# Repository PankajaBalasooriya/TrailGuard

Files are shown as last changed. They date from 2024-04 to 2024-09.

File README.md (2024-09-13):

## TrailGuard
Trail Guard is a portable device that monitors various environmental parameters, including air and water quality, using a wide range of sensors. This comprehensive monitoring tool is designed to be valuable for both travelers and residents who are concerned about their environmental conditions.. 

## Table of Contents

## Why "Trail Guard"?

## Features
- **Portable**: Trail Guard is a portable device that can be easily carried around.
- **Comprehensive**: Trail Guard monitors a wide range of air and water quality parameters.
- **User-friendly**: Trail Guard is designed to be user-friendly and easy to use.
- **Real-time monitoring**: Trail Guard provides real-time monitoring of environmental parameters.
- **Alert system**: Trail Guard has an alert system that notifies users of any harmful environmental conditions.

## Hardware Specifications
- **Microcontroller**: Atmega328P-AU
- **Sensors**: 
  - Temperature and Humidity Sensor (DHT11)
  - Air Quality Sensor (MQ2)
  - Water Quality Sensor (PH Sensor)
  - TDS Sensor
  - Turbidity Sensor
  - Dust Sensor (GP2Y1010AU0F)
- **Display**: 0.96 inch OLED Display
- **User Interface**: 2 Push Buttons and LED Indicator

## Software Specifications
- **Programming Language**: C++ (Arduino)
- **IDE**: Arduino IDE
- **Libraries**:
  - Adafruit_Sensor
  - Adafruit_GFX
  - Adafruit_SSD1306
  - DHT
- **PCB Design Software**: Altium Designer
- **3D Modelling Software**: SolidWorks





## PCB design
The PCB design of Trail Guard was done using Altium Designer. The PCB design files are available in the `TrailGuard2.0` folder.

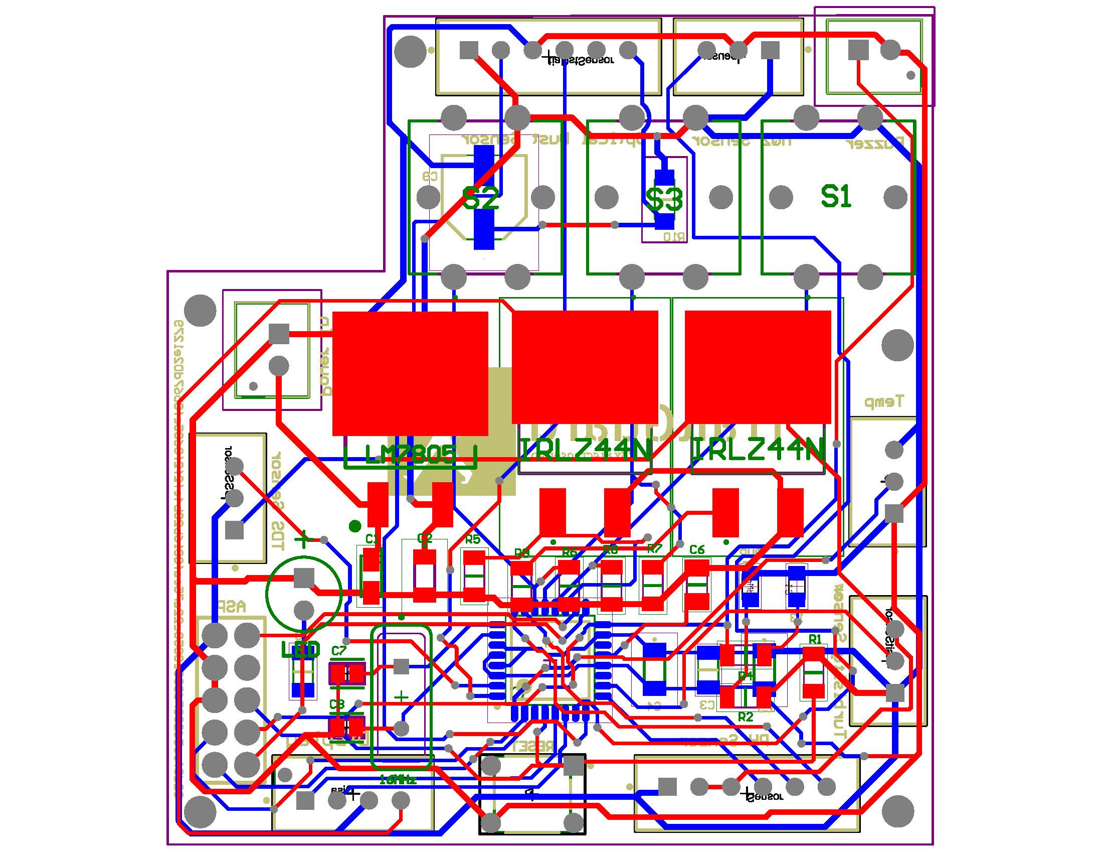
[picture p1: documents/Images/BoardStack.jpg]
PCB Design

<div style="display: flex; justify-content: space-between;">
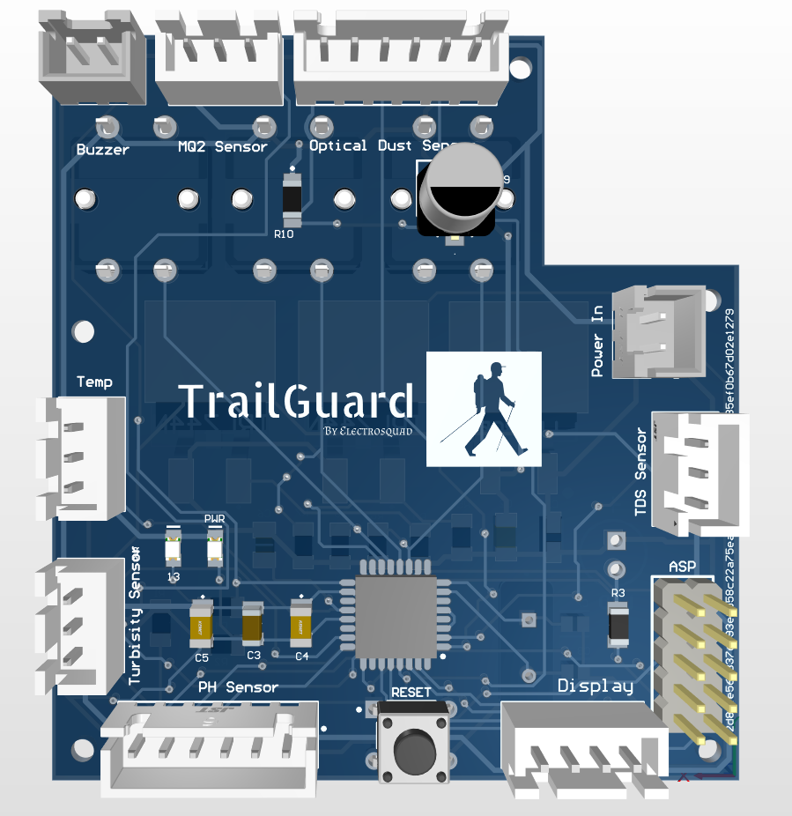
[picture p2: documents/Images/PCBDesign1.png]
    
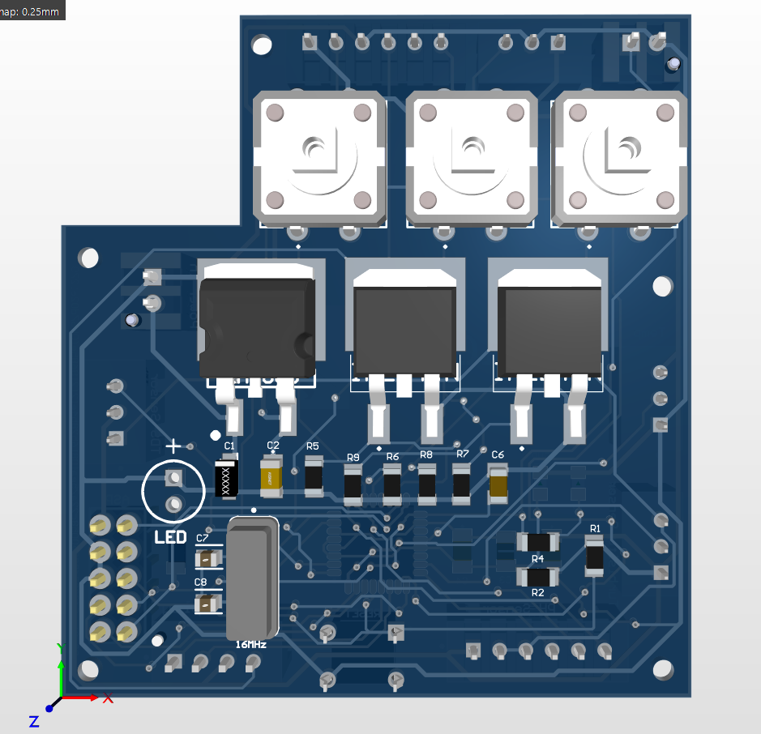
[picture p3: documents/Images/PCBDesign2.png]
    
</div>

## PCB Schematic
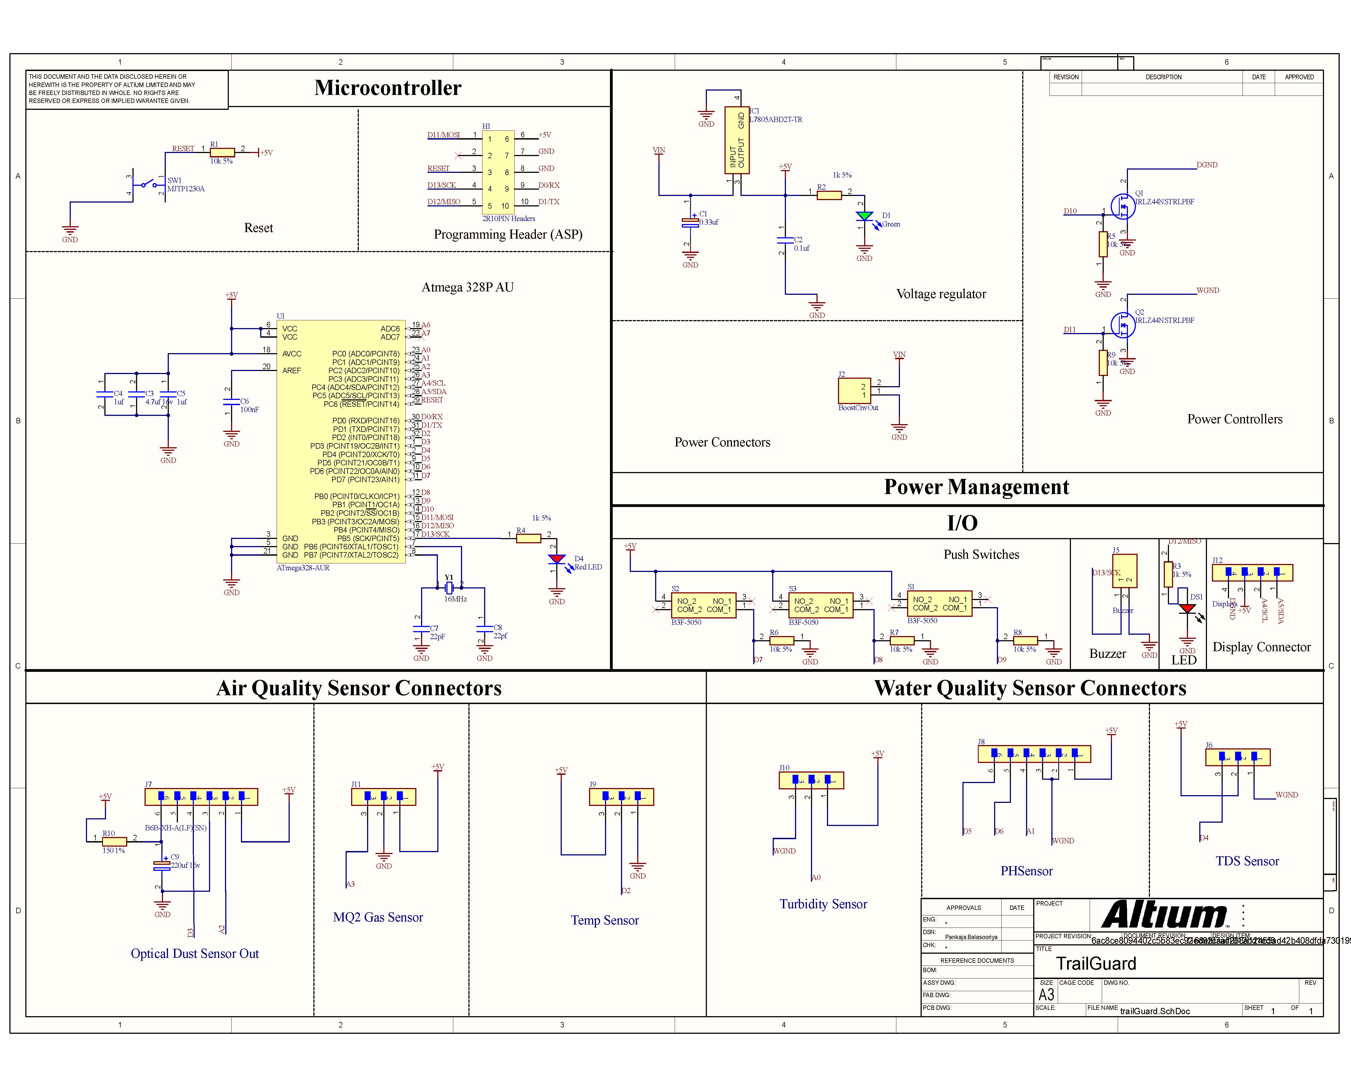
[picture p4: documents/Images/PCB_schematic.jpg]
PCB Schematic


## PCB
<div style="display: flex; justify-content: space-between;">
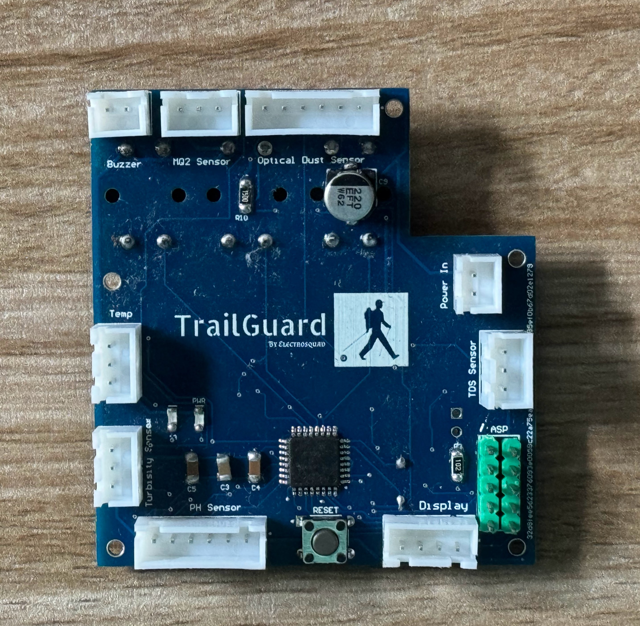
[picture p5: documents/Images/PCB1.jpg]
    
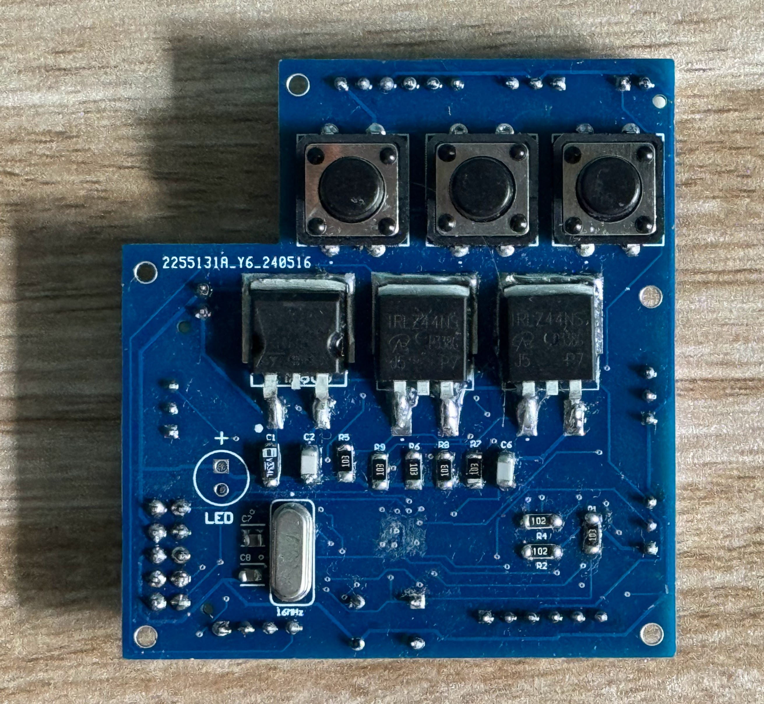
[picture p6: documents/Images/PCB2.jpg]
    
</div>

## SolidWorks Design
<div style="display: flex; justify-content: space-between;">
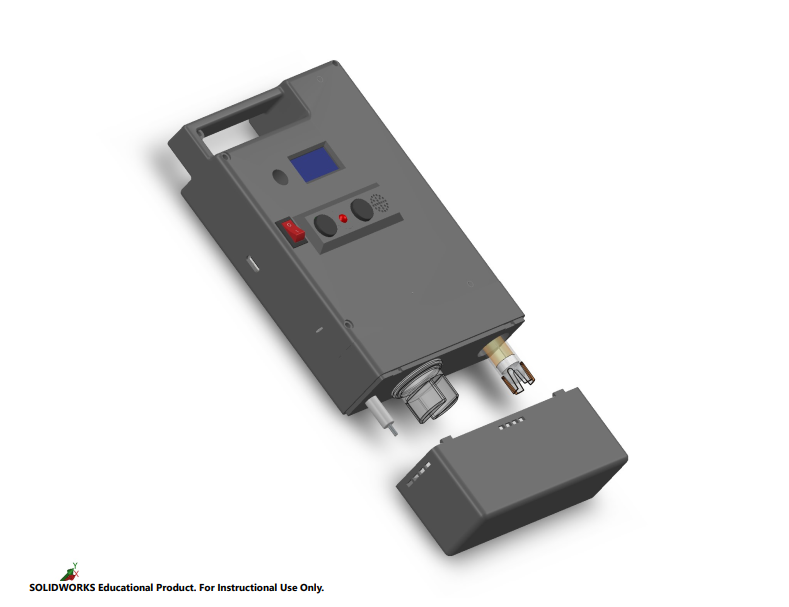
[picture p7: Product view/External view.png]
    
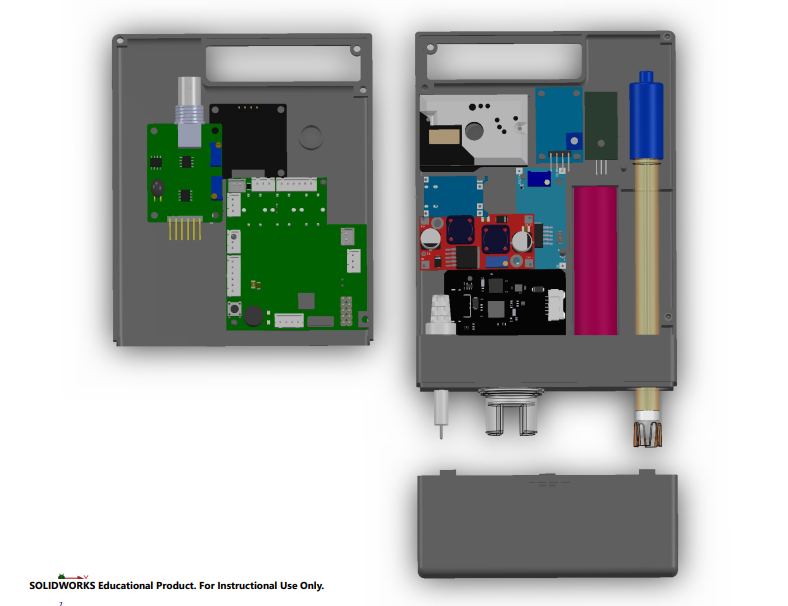
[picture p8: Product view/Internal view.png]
    
</div>

## Product View
<div style="display: flex; justify-content: space-between;">
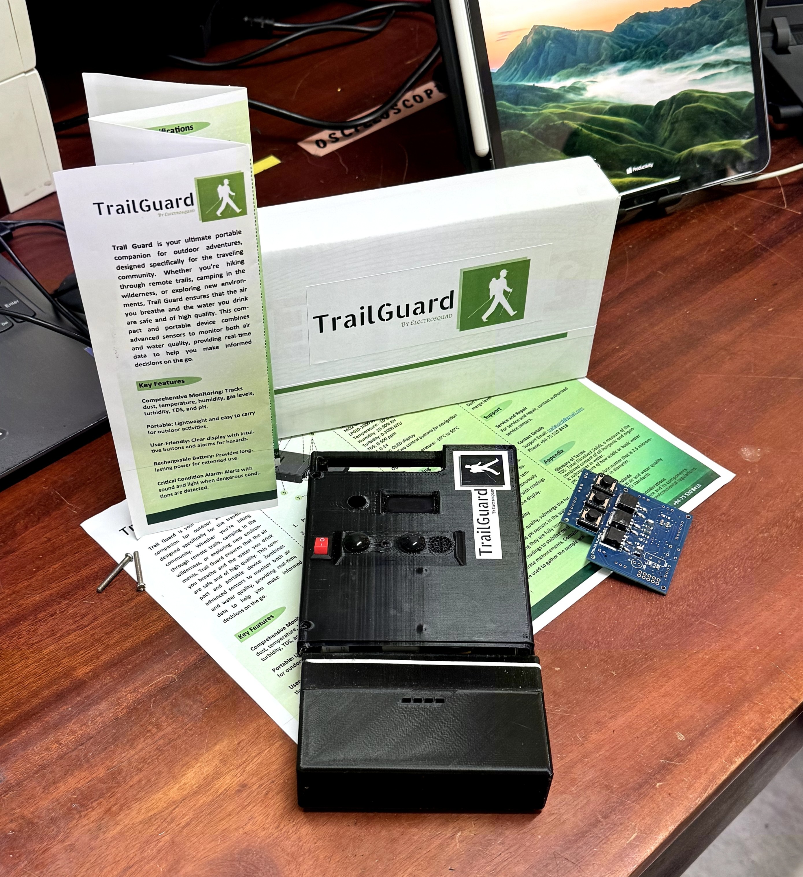
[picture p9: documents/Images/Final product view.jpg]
    
    
</div>

## Team Members
| Name | Index Number |Email|
|---|---|---|
| Balasooriya B A P I | 220054N | balasooriyabapi.22@uom.lk |
| Dewasumithra M P O | 220112R| dewasumithrampo.22@uom.lk |
| Dineshara M C | 220128V |dinesharamc.22@uom.lk|
| Diunugala C H | 220143L | diunugalach.22@uom.lk |

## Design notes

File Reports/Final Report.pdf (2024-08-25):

Department of Electronic and Telecommunication Engineering

## University of Moratuwa, Sri Lanka

EN 1190 - Engineering Design Project

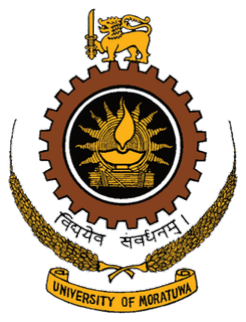
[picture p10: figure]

# TrailGuard

by

# Electrosquad

Balasooriya B A P I | 220054N
Dewasumithra M P O | 220112R
Dineshara M C | 220128V
Diunugala C H | 220143L

## August 25, 2024

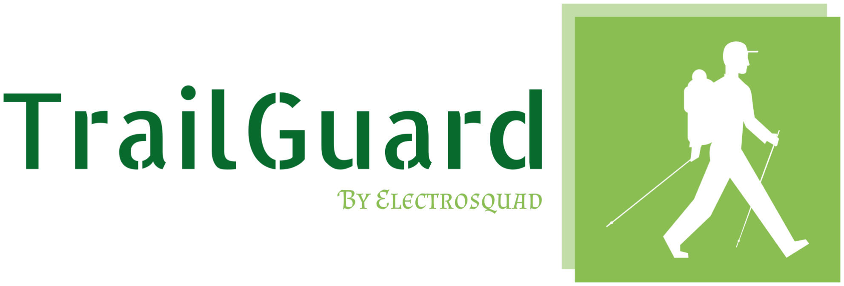
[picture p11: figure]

## Contents

1 Problem Description | 4
2 Feasibility | 6
3 Applications | 7
4 Product Architecture | 8
5 Design and Product Enclosure | 10
6 PCB | 11
7 Final Product | 13
8 Marketing Strategy | 14
9 Task Allocation | 15

10 Project Budget | 15
11 Resources | 16
12 References | 16

## 1 Problem Description

### 1.1 Problem

In today’s rapidly changing environment, outdoor enthusiasts such as hikers, cavers, and travelers face increasing challenges related to environmental conditions. The quality of air and water is not always visible, yet it plays a crucial role in health and safety. Hikers often encounter water sources during their journeys, but determining whether the water is safe for drinking or swimming is difficult without proper equipment. Additionally, exposure to harmful gases, especially in caves or enclosed spaces, can be hazardous. The lack of portable, comprehensive solutions that monitor these vital environmental parameters poses a significant risk to those who venture into nature.

### 1.2 Solution

TrailGuard is a portable device designed to address these challenges by providing real-time monitoring of key environmental parameters such as air quality, water quality, temperature, and humidity. Equipped with a range of sensors, including a TS-300B turbidity sensor, PH4502C pH sensor, DHT11 temperature and humidity sensor, Sharp GP2Y1010AU0F dust sensor, and MQ2 gas sensor, TrailGuard offers a comprehensive solution for assessing environmental conditions. The device also includes a buzzer and LED indicator to alert users to potential dangers, making it a valuable addition to any hiker’s gear. The Atmega328P-AU microcontroller serves as the brain of the device, ensuring efficient operation and control over the various sensors and user interfaces.

### 1.3 Motivation

The motivation behind TrailGuard stems from the growing need for safety and awareness among outdoor enthusiasts. With the increasing popularity of hiking, caving, and other outdoor activities, there is a rising demand for reliable tools that can help individuals assess and respond to environmental risks. TrailGuard aims to empower users with the knowledge they need to make informed decisions about the air they breathe, the water they encounter, and the overall environmental conditions during their adventures. By providing a portable, user-friendly solution, TrailGuard enhances the safety and enjoyment of outdoor experiences.

### 1.4 Justification

The development of TrailGuard is justified by the clear demand for a compact, reliable device that addresses multiple environmental concerns in one package.
To validate the problem and understand the needs and preferences of potential users, we conducted a survey among hikers, adventurers, and students across universities in Sri Lanka. Out of 150 responses, we randomly selected 100 samples for analysis.

80%

20%

Yes
No

Number of people who faced issues due to contaminated air and water

95%
5%

Yes
No

Number of people who like to own a product like our design

93%
7%

Yes
No

Number of people thinks our product will enhance their experience

The survey revealed significant concerns about environmental safety during outdoor activities. Notably, 80% of respondents reported facing issues due to contaminated air and water while traveling. Despite this, only one respondent owned a device capable of measuring water quality.
The majority of participants (95%) expressed a strong interest in owning a product like TrailGuard, and 93% believed that such a device would enhance their overall travel experience.
Furthermore, our research indicated a lack of existing products that offer the same combination of functionalities as TrailGuard. While there are devices available that measure either water or air quality, they tend to be expensive and lack the comprehensive monitoring capabilities of our design. Additionally, social media research highlighted frequent complaints from tourists in the South Asian region about unknowingly drinking contaminated water, leading to unexpected health issues during their travels.
These factors, combined with the positive feedback from our survey, strongly support the need for TrailGuard. The device’s ability to monitor air and water quality, detect harmful gases, and measure temperature and humidity in a single, portable form factor makes it a valuable tool for enhancing safety and enjoyment during outdoor adventures.

## 2 Feasibility

### 2.1 Technical Feasibility

The project technically feasible, and all resource requirements were met easily.
We Designed the electronic circuits and designed the PCB in altium designer. The PCB was manufactured and assembled by a professional PCB manufacturer (JLC PCB). The software was developed using the Arduino IDE, and the final product was tested for functionality and performance. We used Black PLA to 3D print the enclosure for the device. The device was assembled and tested for fit and functionality.

### 2.1.1 Hardware Feasibility

The hardware components required for TrailGuard are readily available and well-suited for the device’s intended functionality. The core of the system is the Atmega328P-AU microcontroller, a robust and reliable choice for managing multiple sensor inputs and controlling the device’s user interface. The selected sensors, including the TS-300B turbidity sensor, PH4502C pH sensor, DHT11 temperature and humidity sensor, Sharp GP2Y1010AU0F dust sensor, MQ2 gas sensor, and Gravity TDS sensor, are all compatible with the Atmega328P-AU and have been widely used in similar applications.

These sensors have been chosen for their accuracy, reliability, and low power consumption, which is critical for a portable device like TrailGuard. The device also incorporates an OLED display, buttons, a buzzer, and an LED indicator, all of which are easily integrated with the microcontroller. The hardware design also includes power-saving features, such as the ability to turn off the display and water sensors when not in use, which extends battery life.

### 2.1.2 Software Feasibility

The software development for TrailGuard primarily involves programming the Atmega328P-AU microcontroller to manage the sensors, process the data, and control the user interface. The microcontroller can be programmed using the Arduino IDE, which is well-documented and widely supported, making it a practical choice for this project.

The software will need to handle real-time data acquisition from multiple sensors, perform basic data processing, and trigger alerts based on predefined thresholds for air and water quality. The user interface, controlled via the OLED display and buttons, will be designed to be intuitive and responsive, allowing users to easily access the information they need. The ability to switch off certain components to conserve power will also be managed through the software.

### 2.2 Economic Feasibility

TrailGuard is designed to be an affordable solution for hikers, adventurers, and residents who are concerned about environmental safety. The components used in the device, such as the Atmega328P-AU microcontroller and various sensors, are cost-effective and widely available, which helps keep the overall production cost low.
By integrating multiple functionalities into a single device, TrailGuard offers significant value compared to purchasing separate devices for air and water quality monitoring, which tend to be more expensive. The cost of producing each unit is competitive, making it feasible to price the device at a level that is accessible to a broad range of customers. Additionally, the modular design and power-saving features contribute to a longer product lifespan, reducing the need for frequent replacements and further enhancing the device’s economic appeal.

## 3 Applications

TrailGuard is a versatile device with a wide range of applications, particularly for outdoor enthusiasts, travelers, and individuals concerned about environmental safety. Below are the primary applications of TrailGuard

### 3.1 Hiking and Outdoor Adventures

One of the primary applications of TrailGuard is for hikers and outdoor adventurers. When exploring remote areas, access to clean water and fresh air can be unpredictable. TrailGuard helps users monitor the quality of water sources they encounter, ensuring that the water is safe for drinking or swimming. Additionally, the device can detect harmful gases and monitor air quality, alerting users to potential dangers, especially in enclosed spaces like caves. The portability and durability of TrailGuard make it an essential part of any hiker’s gear, enhancing safety and providing peace of mind.

### 3.2 Caving and Spelunking

For cavers and spelunkers, air quality is a critical concern due to the potential presence of harmful gases in underground environments. TrailGuard’s gas detection capabilities, combined with its ability to measure temperature and humidity, make it an invaluable tool for those who explore caves. The device’s compact design allows it to be easily carried and attached to gear, ensuring that it is always accessible when needed. The real-time alerts provided by TrailGuard can prevent accidents and health risks associated with poor air quality in these challenging environments.

### 3.3 Environmental Monitoring for Residents

TrailGuard is also valuable for residents in areas where environmental conditions may be a concern. Whether living near industrial zones, in areas with poor air quality, or regions prone to water contamination, residents can use TrailGuard to monitor their immediate environment. The device provides continuous feedback on air and water quality, allowing individuals to take proactive steps to protect their health. Its easy-to-use interface and portable design make it suitable for daily use around the home or in the community.

### 3.4 Travel Safety

Travelers often face uncertainties regarding the quality of air and water in unfamiliar regions. TrailGuard serves as a travel companion, providing crucial information about environmental conditions in real-time. This is particularly useful for tourists visiting regions where water quality may be compromised or where air pollution levels are high. By carrying TrailGuard, travelers can avoid potential health issues related to contaminated water or poor air quality, making their trips safer and more enjoyable.

### 3.5 Educational and Research Purposes

TrailGuard can also be utilized in educational settings and research projects focused on environmental science. Students and researchers can use the device to collect data on air and water quality in various environments. The portability and ease of use make it an excellent tool for field studies, allowing users to gather accurate and reliable data without the need for complex equipment. This application extends TrailGuard’s utility beyond personal safety, contributing to broader efforts in environmental monitoring and education.

## 4 Product Architecture

TrailGuard is designed with a modular architecture that integrates various hardware components and software systems to monitor environmental parameters efficiently. The architecture of TrailGuard can be broken down into the following key components

### 4.1 Hardware Architecture

The hardware architecture of TrailGuard is composed of several critical components that work together to collect, process, and display environmental data. The block diagram below illustrates the key hardware components and their interactions.

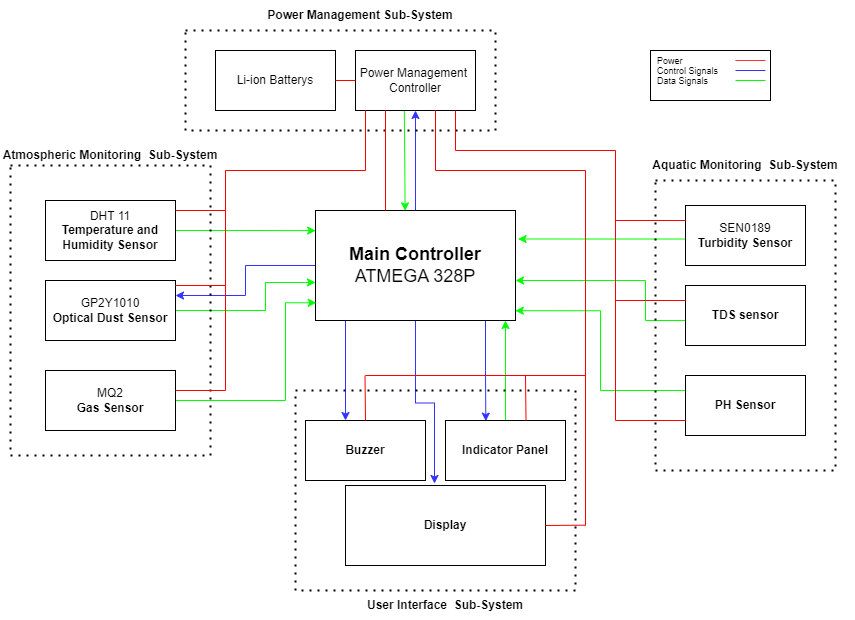
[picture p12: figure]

Figure 1: Block Diagram of TrailGuard Hardware Architecture

### 4.1.1 Microcontroller

The Atmega328P-AU microcontroller serves as the central processing unit of TrailGuard. It manages the operation of sensors, processes the data, and controls the output devices such as the OLED display, buzzer, and LED indicator.

### 4.1.2 Sensors

Sensor | Description
TS-300B Turbidity Sensor | Measures the turbidity (cloudiness) of water to assess its quality.
PH4502C pH Sensor | Measures the pH level of water to determine its acidity or alkalinity.
DHT11 Temperature and Humidity Sensor | Monitors the ambient temperature and humidity levels.
Sharp GP2Y1010AU0F Dust Sensor | Detects the concentration of dust & pollen particles in the air.
MQ2 Gas Sensor | Detects the presence of harmful gases such as carbon monoxide and smoke.
Gravity TDS Sensor | Measures the Total Dissolved Solids (TDS) in water, providing an indication of water purity.

### 4.1.3 Input/Output (IO) Devices

I/O device | Description
Buttons | Two buttons are used for navigating the user interface and controlling device functions.
Buzzer | Serves as an audible alert system, warning users of dangerous environmental conditions.
LED Indicator | Provides visual alerts, complementing the buzzer for immediate awareness.
OLED Display (0.96”) | Provides a visual interface for users to view real-time sensor readings and alerts. It is compact, energy-efficient, and easy to read even in bright outdoor conditions.

### 4.1.4 Power Management

The MOSFET circuit allows selective power control, enabling the display and water sensors to be turned off when not in use to conserve battery life.

### 4.1.5 Power Source

TrailGuard is powered by a 3200mAh 18650 Li-ion rechargeable battery, optimized for prolonged use during outdoor activities.

### 4.2 Software Architecture

The software architecture of TrailGuard is designed to be efficient, user-friendly, and responsive.

### 4.2.1 Firmware

The microcontroller is programmed with firmware that handles sensor data acquisition, processing, and output control. The firmware is developed using the Arduino IDE and tools, taking advantage of its extensive library support and ease of use.

### 4.2.2 Sensor Data Processing

The firmware continuously collects data from the connected sensors, processes it to filter noise, and compares it against predefined thresholds. If the data indicates a potential hazard (e.g., dangerous gas levels), the system triggers an alert through the buzzer and LED.

Users can also measure each parameter individually by selecting the corresponding menu option on the display. The firmware ensures that the sensor readings are accurate and updated in real-time, providing users with reliable information about their environment.

### 4.2.3 User Interface

The OLED display and buttons create an interactive user interface, allowing users to view current sensor readings, navigate through menus, and configure device settings. The interface is designed to be intuitive, with clear visual cues and simple navigation.

### 4.2.4 Alert System

The software is programmed to trigger alerts based on specific environmental conditions. For example, the presence of harmful gases will activate the buzzer and LED indicator, ensuring users are immediately informed.

## 5 Design and Product Enclosure

### 5.1 Design Overview

The design of TrailGuard is centered around portability, durability, and user-friendliness. As a device intended for outdoor use, it is essential that TrailGuard is compact, lightweight, and robust enough to withstand the rigors of various environments, whether on a hiking trail, in a cave, or during travel. The design also focuses on integrating all necessary components in a way that maximizes functionality while minimizing size and weight.

### 5.2 Enclosure Design

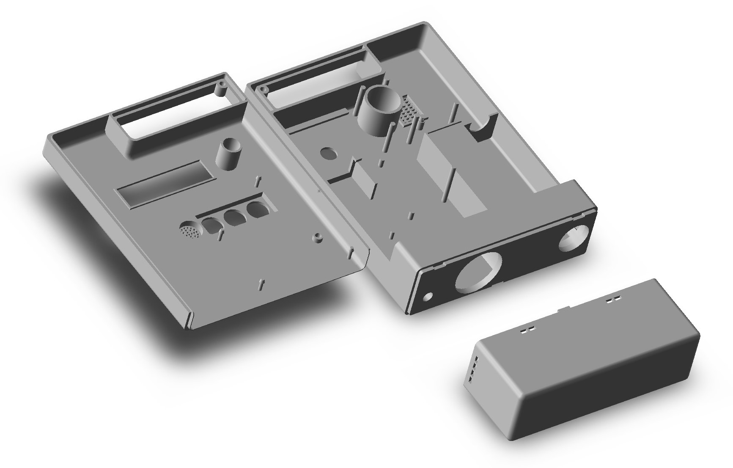
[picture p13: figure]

Figure 2: Block Diagram of TrailGuard Hardware Architecture

### 5.3 Mounting and Portability

To enhance portability, TrailGuard includes a built-in clip or loop that allows it to be securely attached to a backpack. This ensures that the device is always within reach and can be easily monitored without needing to be held or stored in a pocket. The attachment mechanism is designed to be sturdy, preventing accidental detachment during vigorous activities such as hiking or climbing.

## 6 PCB

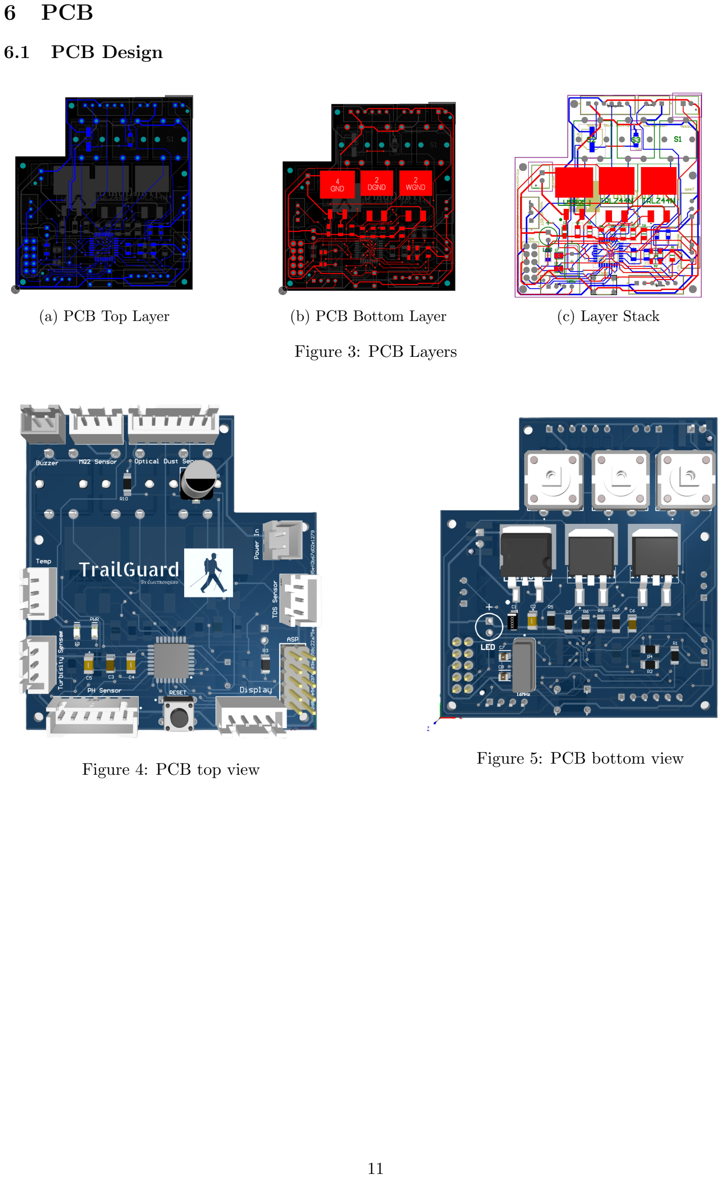
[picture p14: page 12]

### 6.1 PCB Design

(a) PCB Top Layer | (b) PCB Bottom Layer | (c) Layer Stack

Figure 3: PCB Layers

Figure 4: PCB top view | Figure 5: PCB bottom view

### 6.2 PCB Schematic

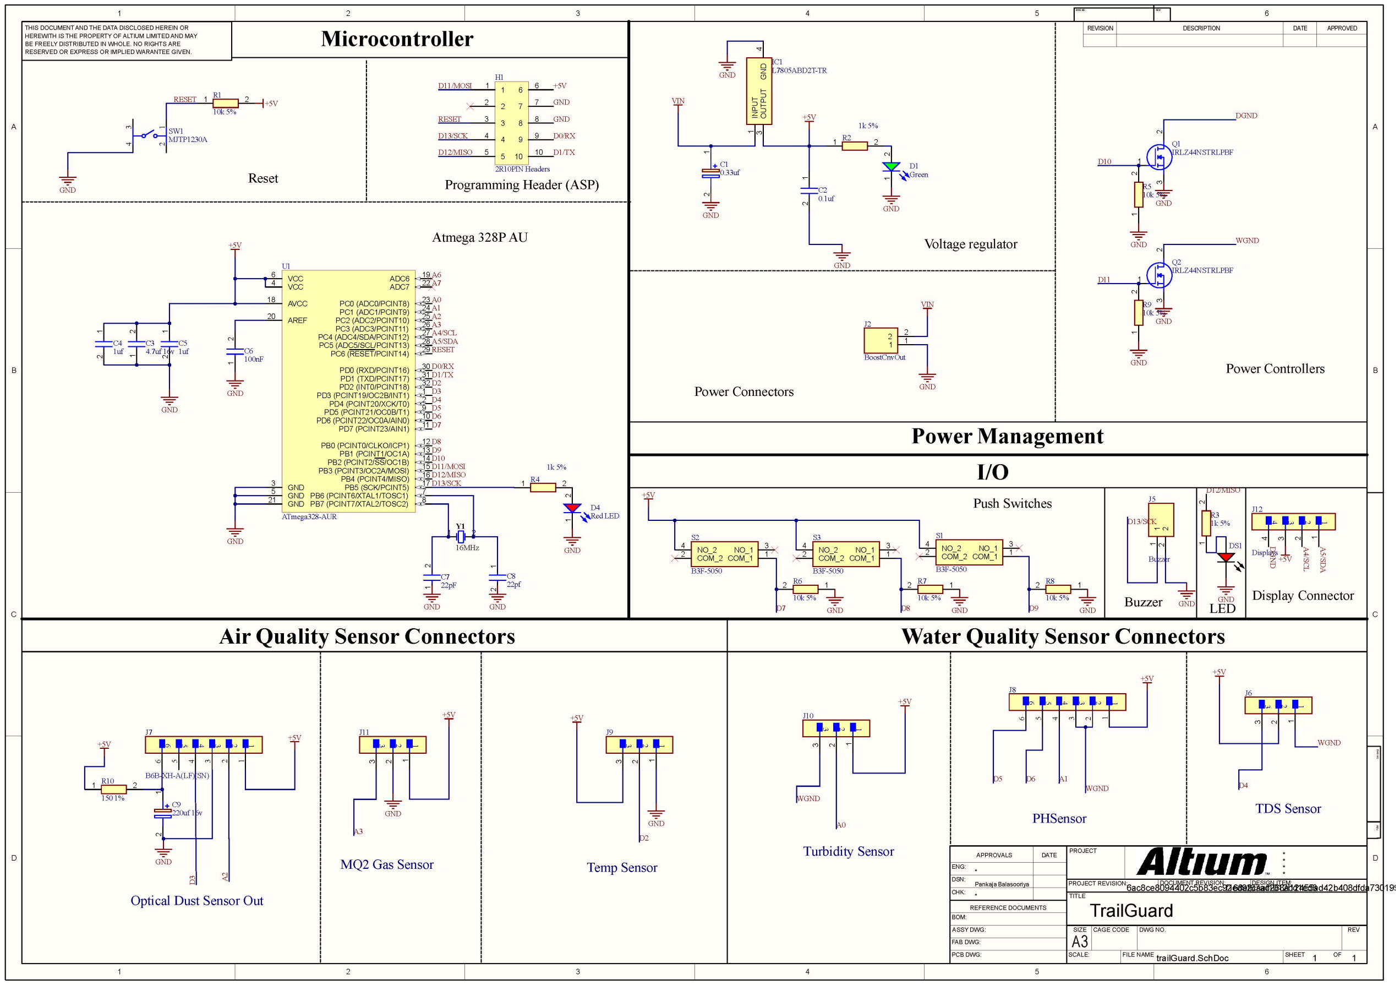
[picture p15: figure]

Figure 6: PCB Schematic

## 7 Final Product

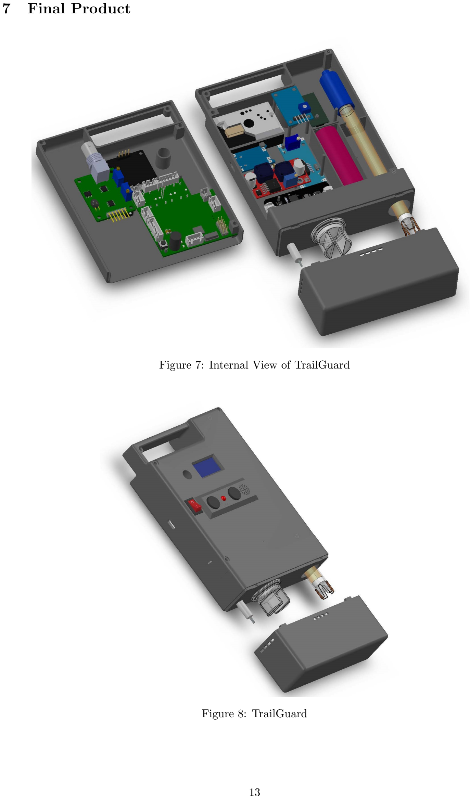
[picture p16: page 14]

Figure 7: Internal View of TrailGuard

Figure 8: TrailGuard

## 8 Marketing Strategy

### 8.1 Marketing Strategy

### 8.1.1 Target Market

TrailGuard is primarily aimed at outdoor enthusiasts, such as hikers, campers, adventurers, and travelers who are concerned about environmental safety. Additionally, it targets residents living in areas with potential air and water quality issues, as well as educational institutions and research organizations involved in environmental monitoring. The device appeals to individuals who prioritize safety, convenience, and reliable environmental monitoring tools.

### 8.1.2 Value Proposition

TrailGuard offers a unique value proposition by combining multiple environmental monitoring functions—such as air and water quality detection, temperature, humidity measurement, and gas detection—into a single, portable device. Its compact design along with user-friendly features and easy-to-navigate interface, makes it a versatile tool for outdoor activities and daily use. Compared to existing products that only monitor either air or water quality, TrailGuard provides a comprehensive solution at a competitive price point, ensuring a high return on investment for customers.

### 8.1.3 Marketing Channels

To reach the target audience effectively, the marketing strategy will leverage multiple channels

a) Digital Marketing
Utilize social media platforms, outdoor adventure forums, and targeted online advertising to create awareness among potential customers. A dedicated website will provide detailed product information, customer testimonials, and a platform for direct purchases.
b) Partnerships
Collaborate with outdoor gear retailers and environmental organizations to promote TrailGuard. These partnerships can include co-branded marketing campaigns, product placements, and joint events.
c) Content Marketing
Develop educational content such as blogs, videos, and tutorials that highlight the importance of environmental monitoring and demonstrate how TrailGuard can enhance outdoor experiences. Content will be shared across social media, YouTube, and relevant blogs.
d) Influencer Marketing
Engage with influencers in the outdoor adventure and travel communities to showcase TrailGuard in real-world scenarios. Their endorsements can help build credibility and attract a wider audience.

### 8.1.4 Pricing Strategy

TrailGuard will be priced competitively to ensure accessibility to a broad range of customers. The pricing strategy will consider the cost of production, competitor pricing, and the perceived value of the product. To attract early adopters, a limited-time discount may be offered during the product launch phase.

## 9 Task Allocation

The workload is equally distributed among the team members, with each member responsible for specific tasks based on their expertise and interests. The task allocation is as follows

Name | Index Number | Task
Balasooriya B A P I | 220054N | PCB Design and Circuit Design
Dewasumithra M P O | 220112R | Enclosure Design and Circuit Designing
Dineshara M C | 220128V | Programming and Enclosure Design
Diunugala C H | 220143L | Programming and PCB Design

Table 1: Task Allocation

## 10 Project Budget

### 10.1 Production Cost for a single unit

Item | Unit Price (LKR) | Quantity | Total Cost (LKR)
Atmega328p-AU | 631.74 | 1 | 631.74
TS-300B Turbidity Sensor | 2,566.86 | 1 | 2,566.86
PH4502C pH Sensor | 3,250.00 | 1 | 3,250.00
DHT11 Sensor | 230.00 | 1 | 230.00
Sharp GP2Y1010AU0F Sensor | 1,470.00 | 1 | 1,470.00
MQ2 Gas Sensor | 410.00 | 1 | 410.00
Gravity TDS Sensor | 2,350.00 | 1 | 2,350.00
OLED Display (0.96”) | 600.00 | 1 | 600.00
IRLZ44NSTRL MOSFET | 150.00 | 2 | 300.00
Buttons and LEDs | 100.00 | 1 | 100.00
Buzzer | 50.00 | 1 | 50.00
Enclosure | 3,120.00 | N/A | 3,120.00
Rechargeable Battery | 760.00 | 1 | 760.00
PCB Fabrication | 570.00 | 1 | 570.00
Miscellaneous Components | 2,000.00 | N/A | 2,000.00
Packaging | 300 | 1 | 300.00
Total Estimated Budget | 18708.60

Table 2: Project Budget for TrailGuard

Per unit cost can be reduced by 20% ordering components in bulk and further development by reducing the physcial size. Also cost can be furthur reduced by combining seperate modules and using a single probe for all readings.

### 10.2 Marketing Budget

Marketing budget for TrailGuard per month is estimated as follows

Item | Estimated Cost (LKR)
Digital Marketing | 10,000.00
Content Marketing | 3,000.00
Influencer Marketing | 2,000.00
Total Estimated Budget | 15,000.00

Table 3: Marketing Budget for TrailGuard

## 11 Resources

1. GitHub Repository:
https://github.com/PankajaBalasooriya/TrailGuard
2. User Guide:
https://github.com/PankajaBalasooriya/TrailGuard/blob/main/User%20Guide.pdf

## 12 References

[1] ”National Environmental (Ambient Water Quality) Regulations, No. 01 of 2019,” Gazette Extraordinary of the Democratic Socialist Republic of Sri Lanka, Nov. 5, 2019.
[2] Y. Wang, S. M. S. M. Rajib, C. Collins, and B. Grieve, ”Low-Cost Turbidity Sensor for Low-Power Wireless Monitoring of Fresh-Water Courses,” IEEE Sensors Journal, vol. 18, no. 11, pp. 4689-4696, June 1, 2018.
[3] World Health Organization, ”Guidelines for drinking-water quality,” 4th ed., Geneva: WHO, 2011.
[4] ”pH Sensor Module User Manual,” DFRobot, 2019.
[5] ”DHT11 Digital Temperature and Humidity Sensor,” Adafruit Industries, 2019.
[6] ”GP2Y1010AU0F Dust Sensor,” Sharp Corporation, 2018.
[7] ”MQ-2 Gas Sensor,” SparkFun Electronics, 2019.
[8] ”Gravity: Analog TDS Sensor/Meter for Arduino,” DFRobot, 2019.
[9] ”IRLZ44NSTRL MOSFET Datasheet,” Infineon Technologies, 2019.
[10] ”18650 Li-ion Rechargeable Battery,” Panasonic Corporation, 2019.

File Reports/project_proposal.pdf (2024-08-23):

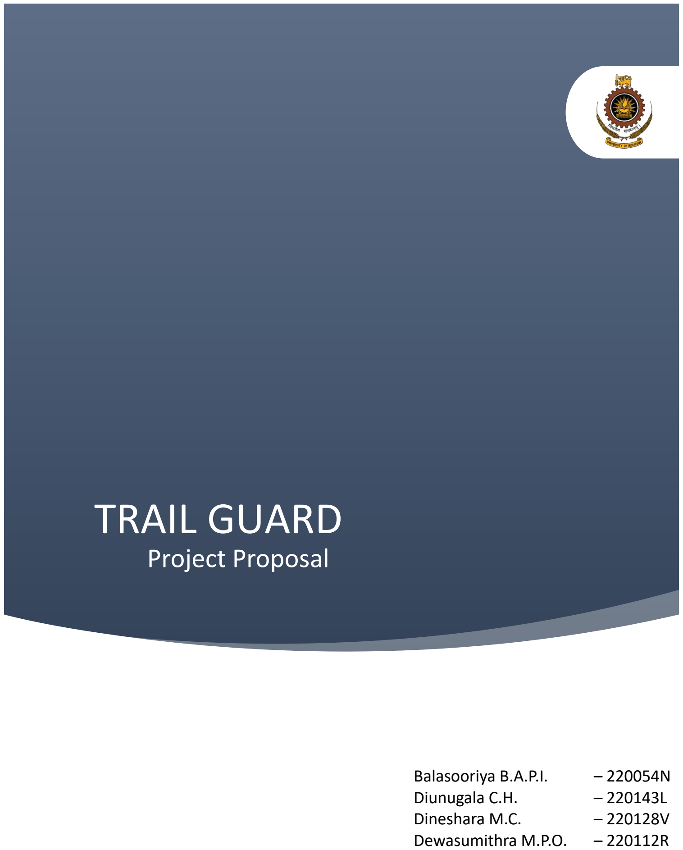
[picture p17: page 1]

# TRAIL GUARD

Balasooriya B.A.P.I. | – 220054N
Diunugala C.H. | – 220143L
Dineshara M.C. | – 220128V
Dewasumithra M.P.O. | – 220112R

# Project Proposal

### Problem Statement

- When traveling, individuals often encounter unfamiliar bathing facilities and water sources, potentially leading to allergies and skin irritation due to contaminated water.
- Exposure to dust and pollen in new environments can trigger breathing difficulties, particularly for those sensitive to airborne particles.

### Objectives

- To ensure a safe environment for drinking and bathing water, as well as high-quality air for a pleasant travel experience.
- To deliver a device with extended battery life for uninterrupted usage and to provide diverse data and functionalities during travel.

### Product Description

- The product is a compact, portable device designed to measure both water and air quality, providing users with immediate feedback.
- Integrated with temperature and humidity sensors, as well as a torch, the device offers a comprehensive solution for evaluating environmental conditions.
- Utilizing a user-friendly display, it presents data collected from the sensors in an easily understandable format.
- The device also features a solar-powered charger to extend its operational duration between charging sessions.

### Market Analysis

- While devices for checking air and water quality exist in the market, they are often non-portable and come with a high price tag. Furthermore, there is a gap in the market as no single device currently fulfills all these purposes.

### Financial Analysis

- The budget estimate outlines the major expenses associated with the following modules, which comprise significant portions of the financial analysis.
Item | Cost (LKR)
Microcontroller | 1400
128X32 OLED Display | 700
Turbidity sensor | 2700
Dust sensor | 1900
Temperature and humidity sensor | 400
Li ion Battery * 3 | 750
Solar cells * 2 | 720
Mini solar batter charging module | 450
Total estimated cost | 9990

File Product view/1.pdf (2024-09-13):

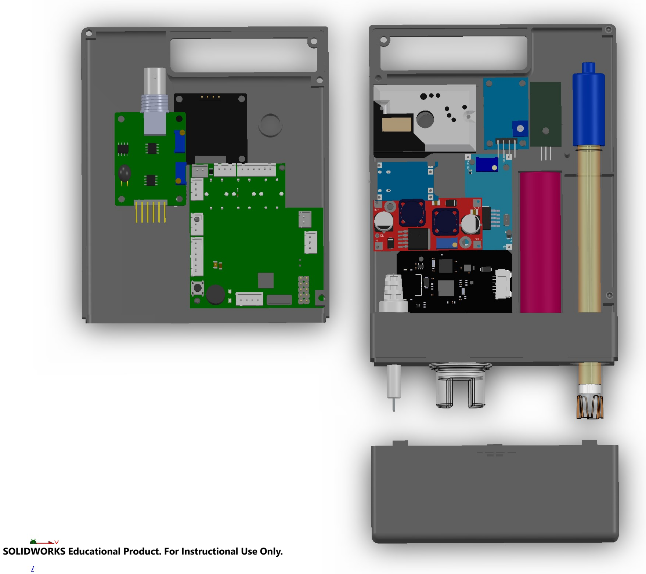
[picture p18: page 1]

SOLIDWORKS Educational Product. For Instructional Use Only.

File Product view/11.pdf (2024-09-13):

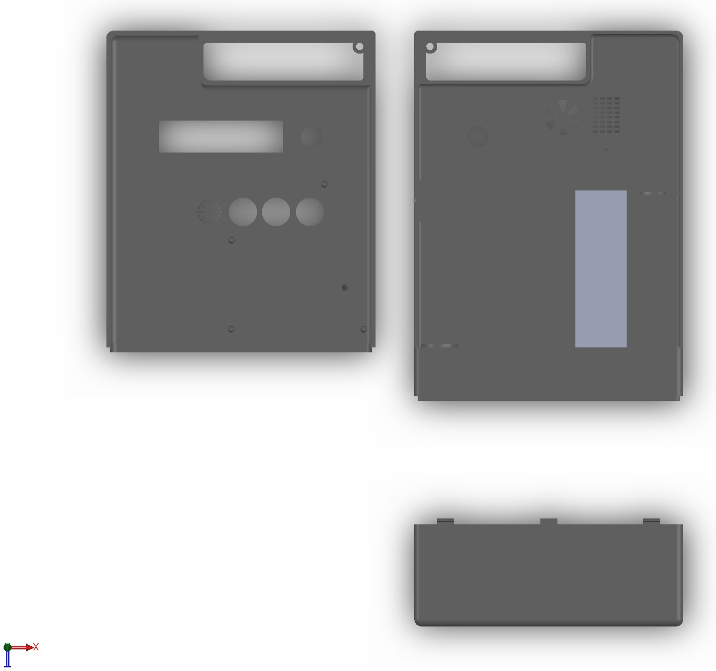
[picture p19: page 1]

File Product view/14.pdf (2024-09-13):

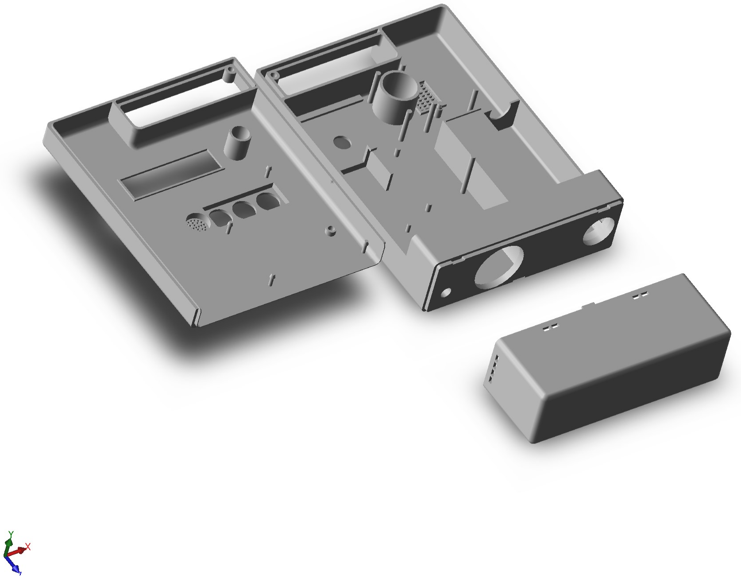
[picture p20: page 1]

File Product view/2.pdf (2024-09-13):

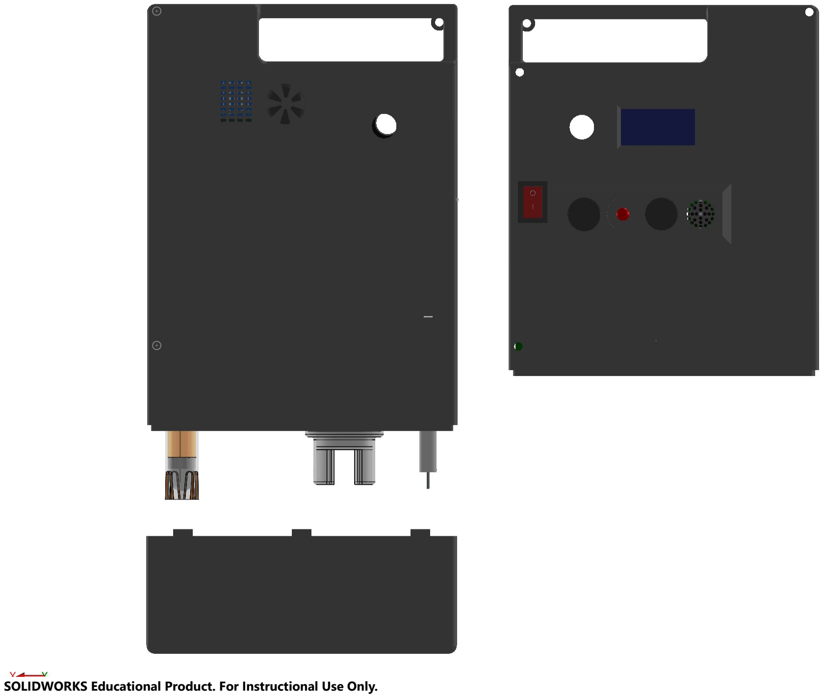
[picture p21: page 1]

SOLIDWORKS Educational Product. For Instructional Use Only.

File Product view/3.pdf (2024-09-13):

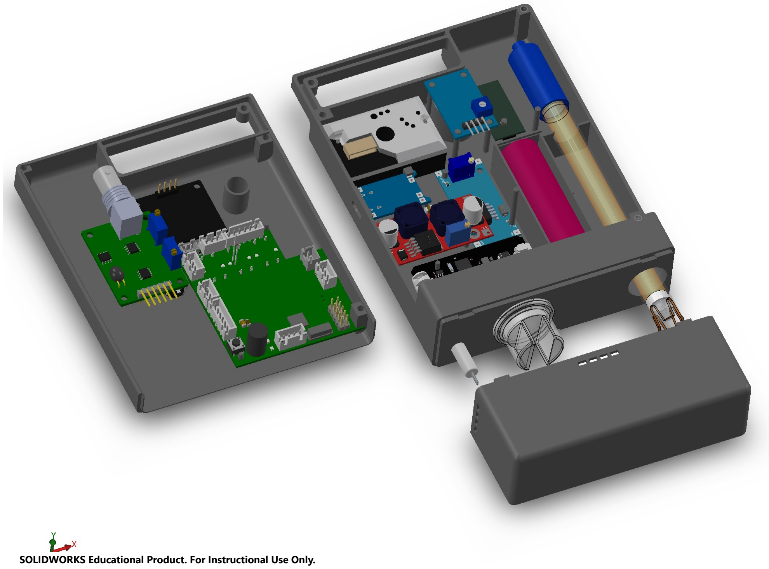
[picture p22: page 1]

SOLIDWORKS Educational Product. For Instructional Use Only.

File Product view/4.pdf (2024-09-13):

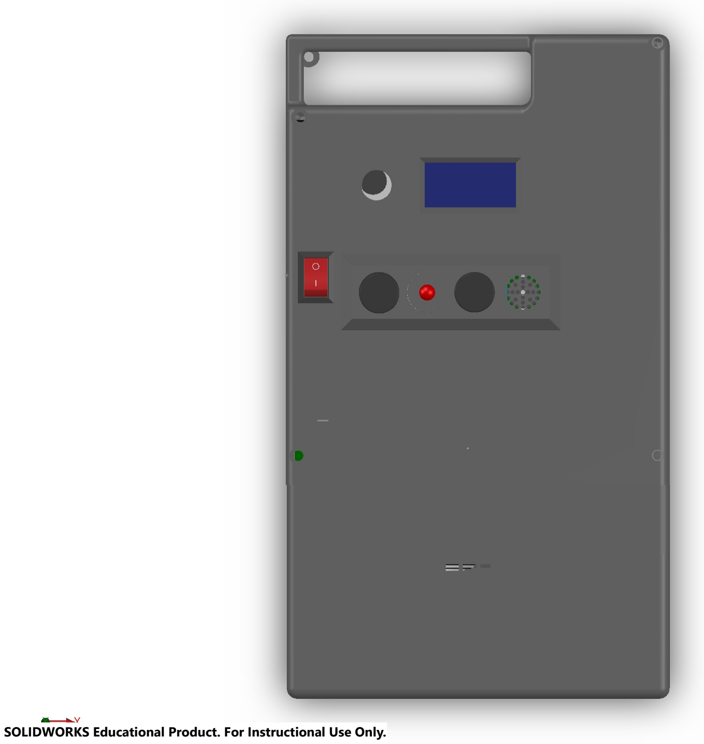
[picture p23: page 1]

SOLIDWORKS Educational Product. For Instructional Use Only.

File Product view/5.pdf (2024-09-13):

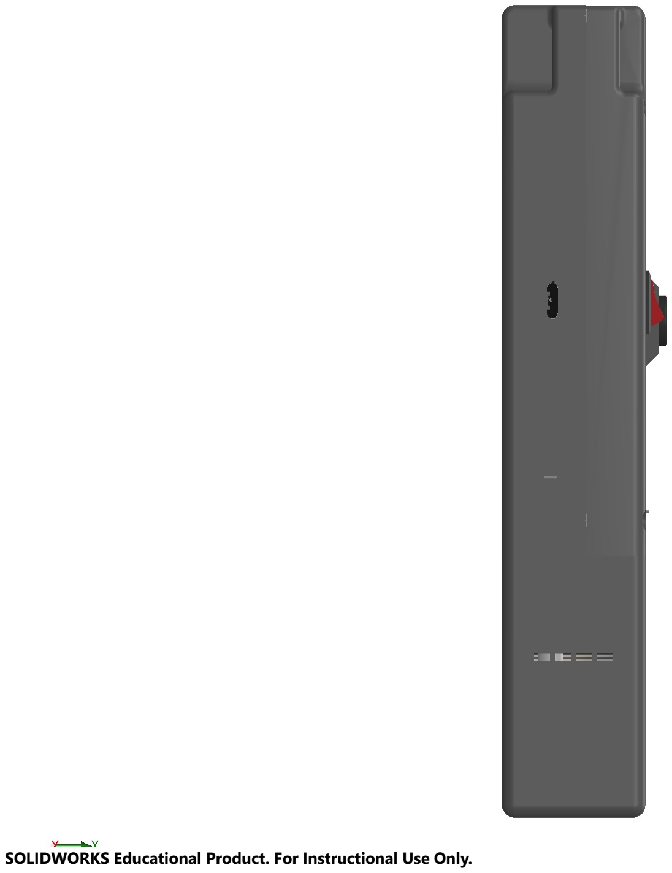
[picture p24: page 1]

SOLIDWORKS Educational Product. For Instructional Use Only.

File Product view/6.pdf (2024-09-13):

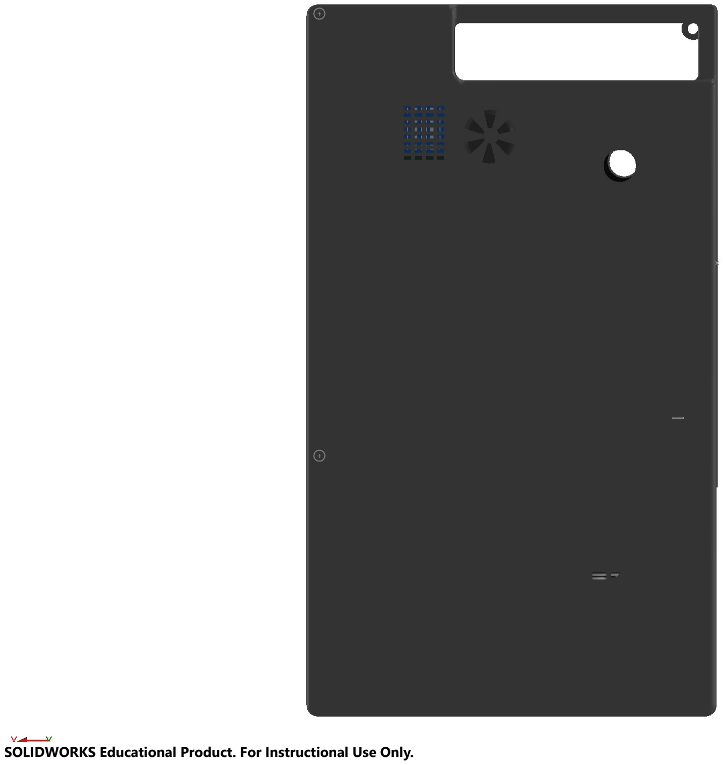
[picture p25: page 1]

SOLIDWORKS Educational Product. For Instructional Use Only.

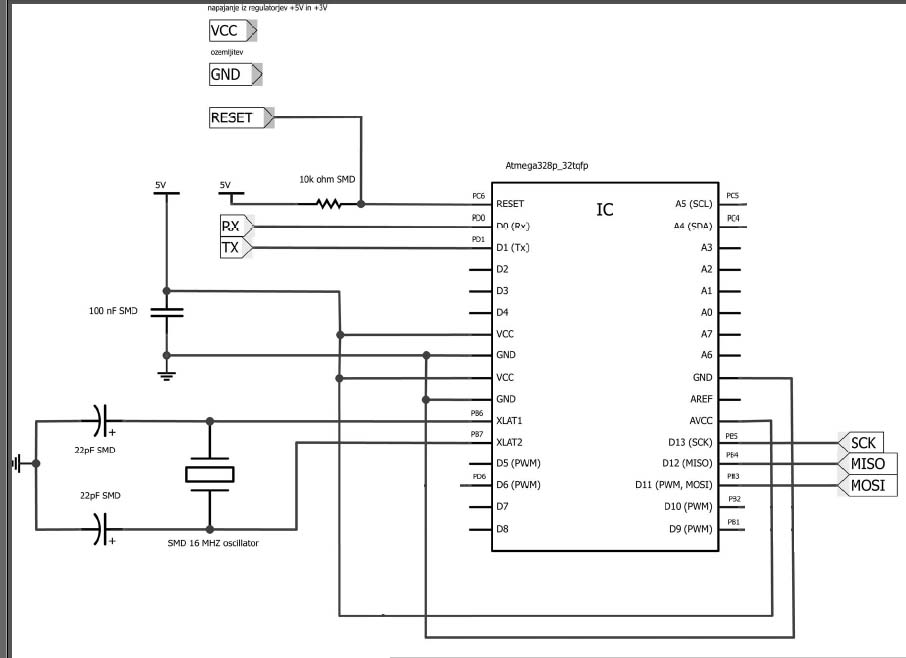
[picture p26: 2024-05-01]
documents/Reference Schematics/new.jpg

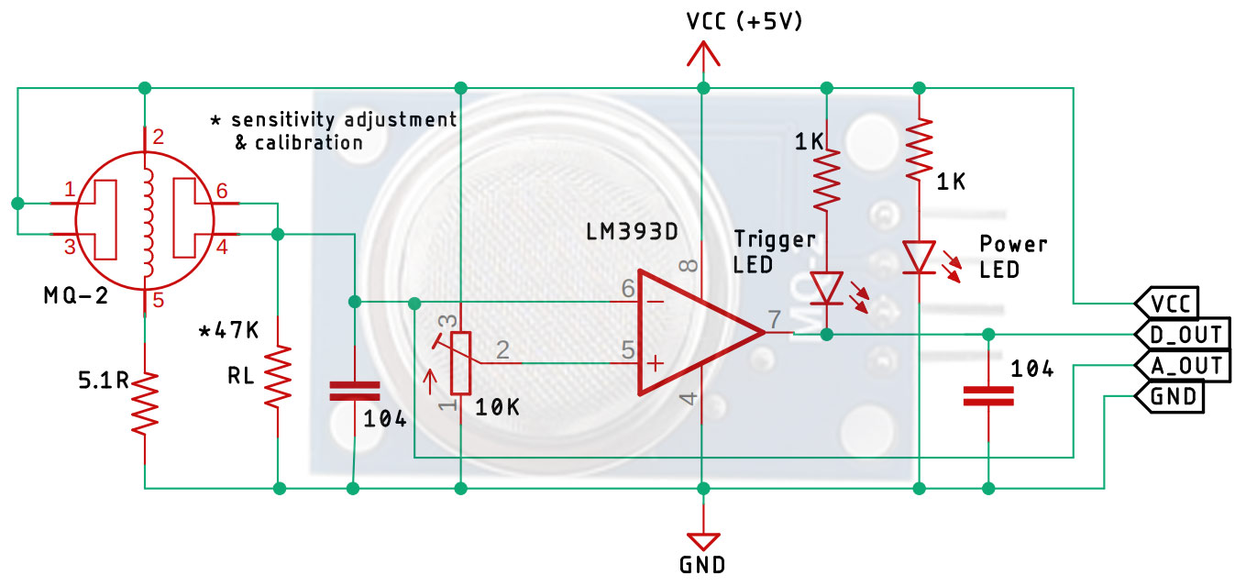
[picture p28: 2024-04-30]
documents/Reference Schematics/Gas-Sensor-Schematic.jpg

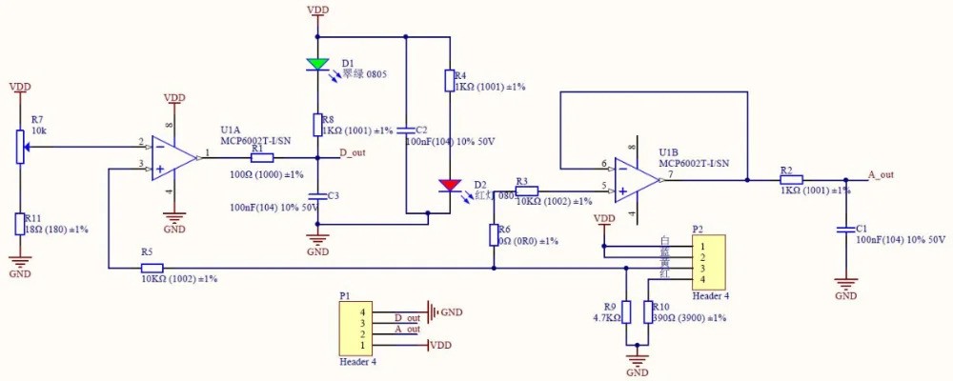
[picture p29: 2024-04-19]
documents/Reference Schematics/H52aba18b9d094bc19128137fca20811fe-ezgif.com-webp-to-jpg-converter.jpg

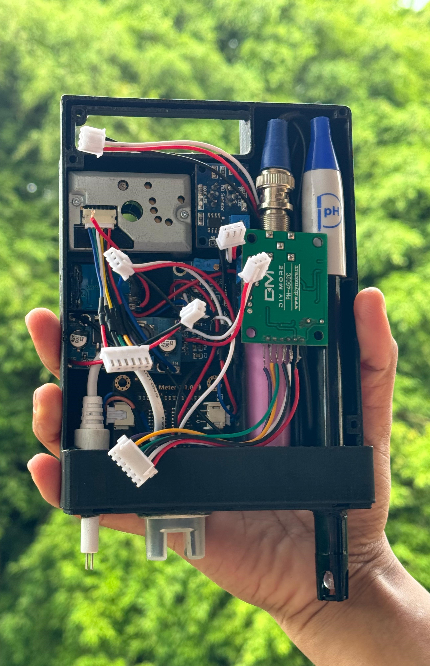
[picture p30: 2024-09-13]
documents/Images/InternalviewBottom.jpg

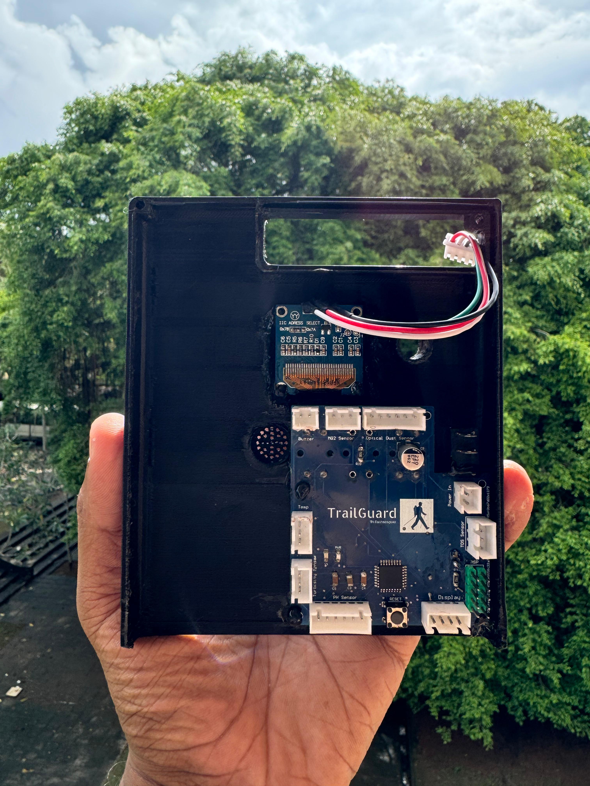
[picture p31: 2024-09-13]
documents/Images/InternalViewTop.jpg

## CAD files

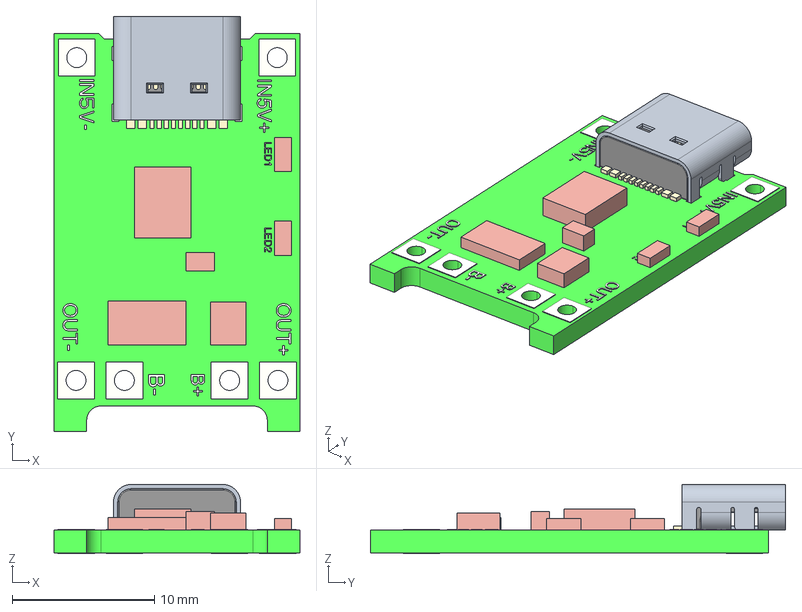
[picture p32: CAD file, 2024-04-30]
documents/3D Parts/tp4056_pcb_asm.stp
17.3 x 29.2 x 4.86 mm
TP4056_PCB
PRT0001
PRT0002
PRT0003
PRT0004
PRT0005 x 2
BOSS-EXTRUDE14_8_
BOSS-EXTRUDE7_4_
BOSS-EXTRUDE7_3_
BOSS-EXTRUDE14_4_
BOSS-EXTRUDE14_2_
BOSS-EXTRUDE14_11_
BOSS-EXTRUDE7_7_
BOSS-EXTRUDE14_9_
BOSS-EXTRUDE14_3_
BOSS-EXTRUDE14_7_
MIRROR2
BOSS-EXTRUDE14_5_
BOSS-EXTRUDE14_12_
BOSS-EXTRUDE7_8_
BOSS-EXTRUDE7_1_
BOSS-EXTRUDE14_10_
BOSS-EXTRUDE7_9_
BOSS-EXTRUDE14_6_
BOSS-EXTRUDE14_1_
BOSS-EXTRUDE7_6_
BOSS-EXTRUDE7_2_
CUT-EXTRUDE5
BOSS-EXTRUDE7_5_

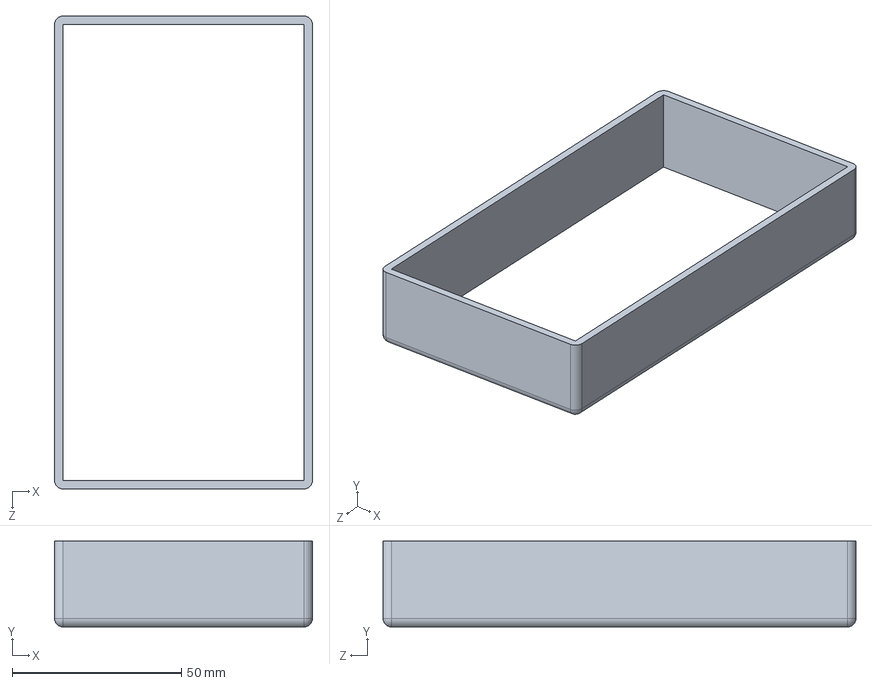
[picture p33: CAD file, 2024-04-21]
documents/3D Designs/Part1.SLDPRT
76.2 x 25.4 x 139.7 mm

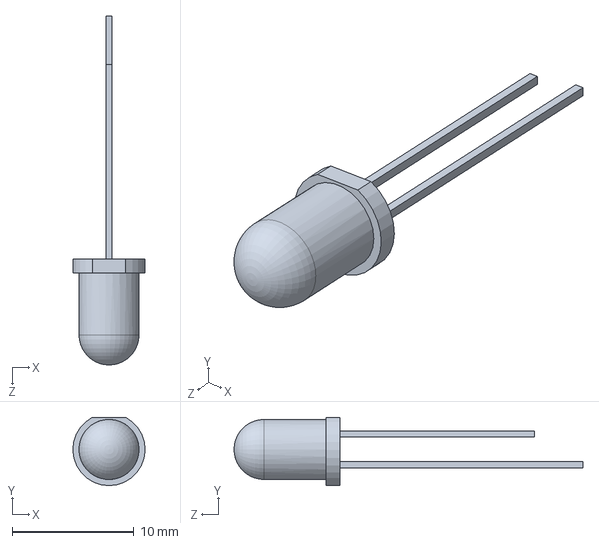
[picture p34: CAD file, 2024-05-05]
documents/3D Parts/red-led-5mm.SLDPRT
5.95 x 5.62 x 28.7 mm

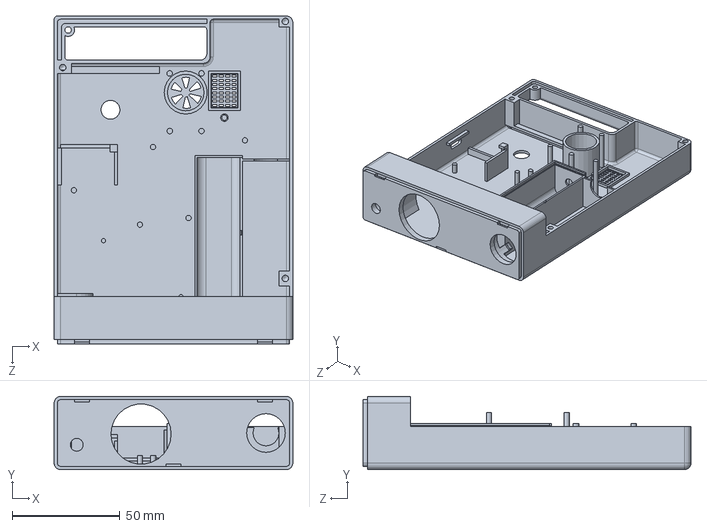
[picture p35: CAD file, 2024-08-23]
Enclosure/bottom.SLDPRT
111.0 x 34.0 x 152.5 mm

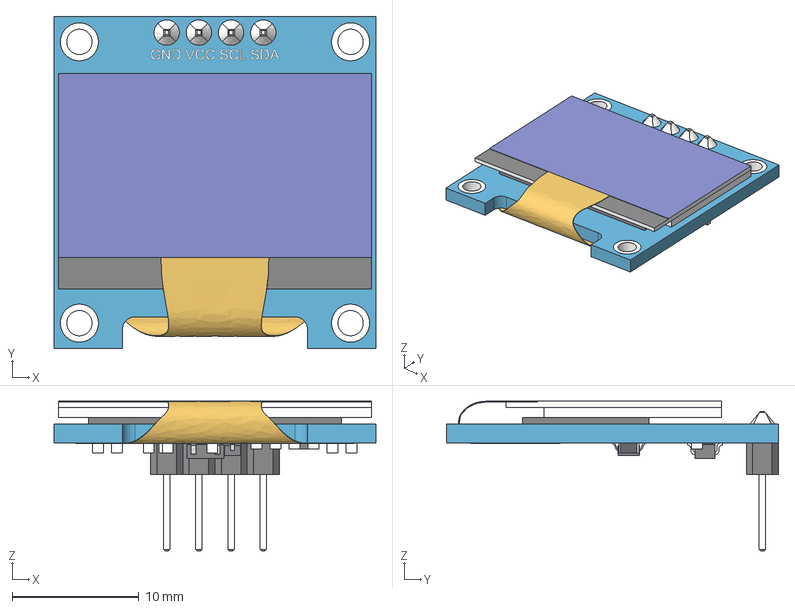
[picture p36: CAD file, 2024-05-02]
documents/3D Parts/SSD1306_OLED_Display(128x64).step
25.4 x 26.2 x 11.8 mm
board
screen
pin_header
soldering
smd_capacitor
smd_capacitor (1)
914_smd_resistor
472_smd_resistor x 3
t4_smd_diode
smd_capacitor (2)
smd_capacitor (3)
smd_capacitor (4)
smd_capacitor (5)
smd_capacitor (6)
472_smd_resistor (1)
SOT-23_XC6206 v3
smd_capacitor (7)
flat_cable

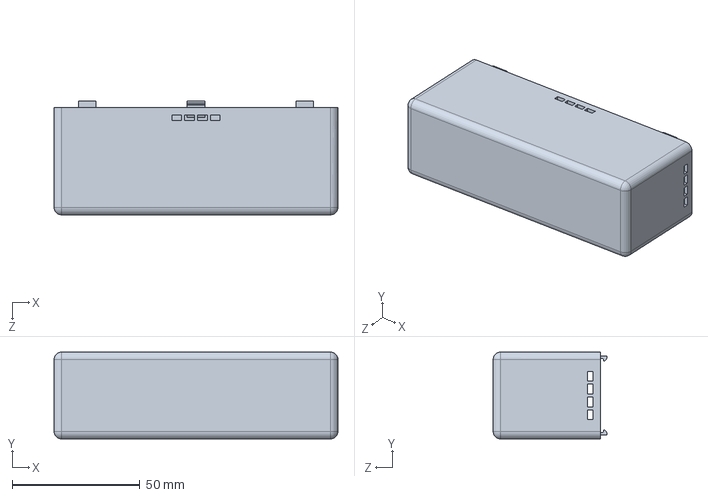
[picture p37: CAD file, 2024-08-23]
Enclosure/cup.SLDPRT
111.0 x 34.0 x 44.5 mm

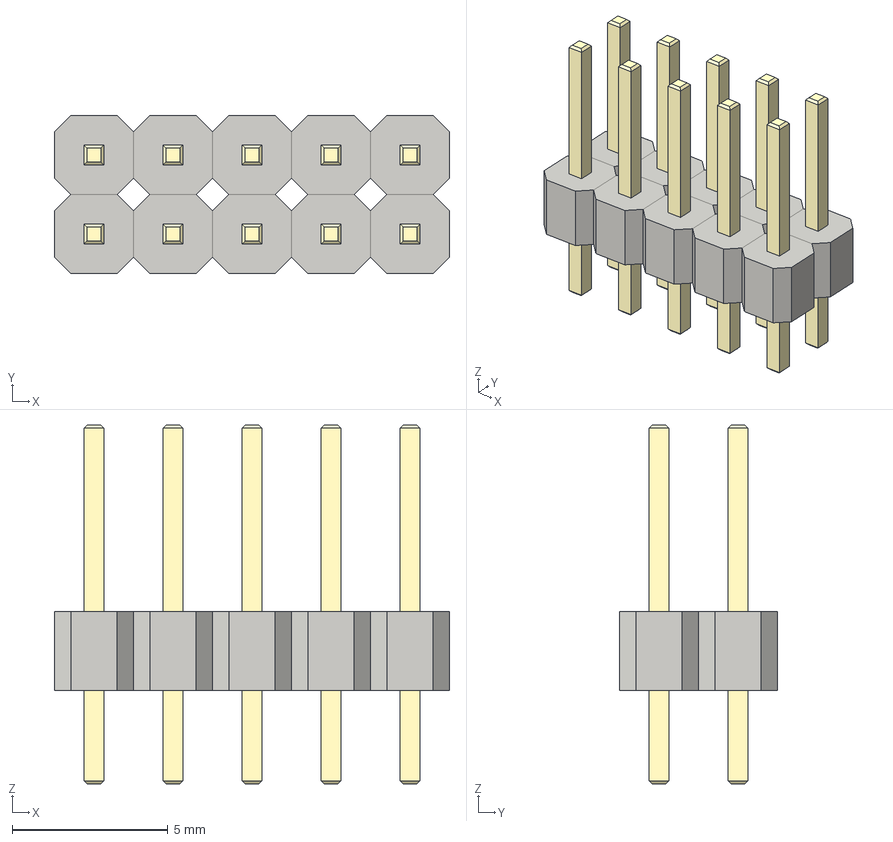
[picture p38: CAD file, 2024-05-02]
documents/3D Parts/Header 10 pins.step
12.7 x 5.08 x 11.5 mm

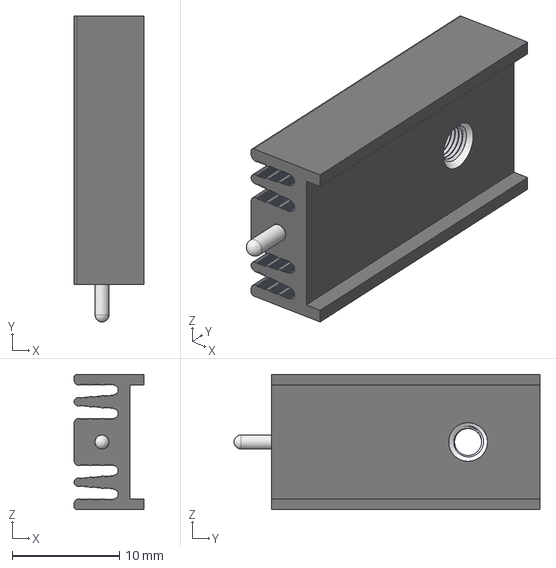
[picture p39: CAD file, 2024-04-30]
documents/3D Parts/Black Heatsink - Dimensions 25 x 12.6 x 6.5 mm. Hole at 18.3mm. Pin fixing.stp
6.50 x 28.5 x 12.6 mm

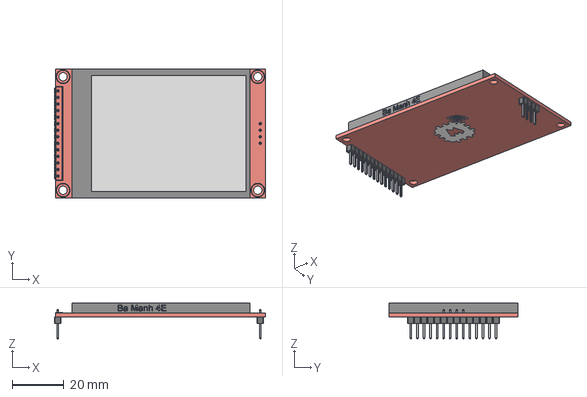
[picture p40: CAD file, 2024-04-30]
documents/3D Parts/TFT LCD 2.8inch ILI9341.step
81.8 x 50.0 x 13.9 mm
1x1_Pin_Header_2.54mm x 14
1x1_Pin_Header_2.54mm_1 x 4

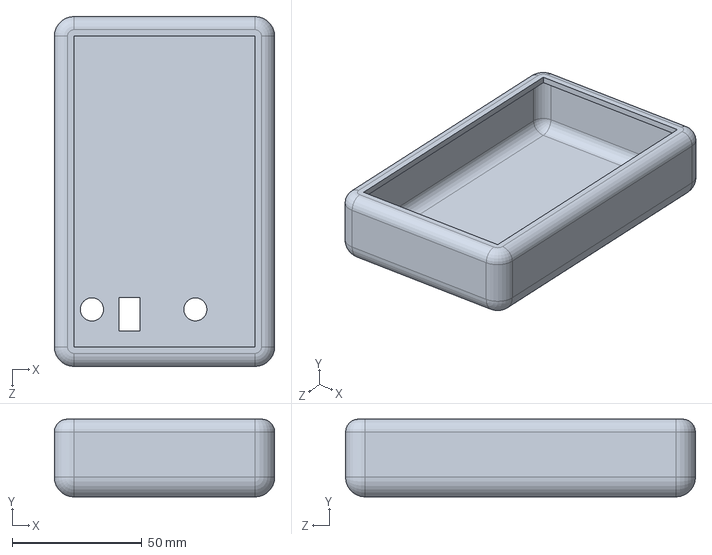
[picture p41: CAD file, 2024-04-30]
documents/3D Parts/Part1.SLDPRT
85.1 x 30.1 x 135.1 mm

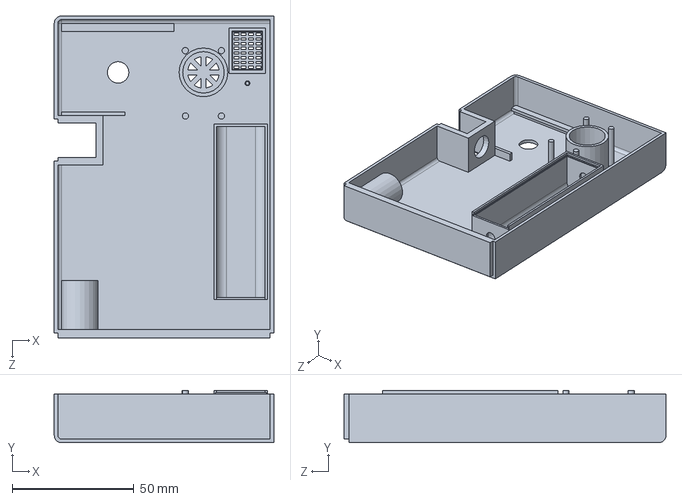
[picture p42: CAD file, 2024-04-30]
documents/3D Parts/newone.SLDPRT
90.0 x 21.5 x 132.0 mm

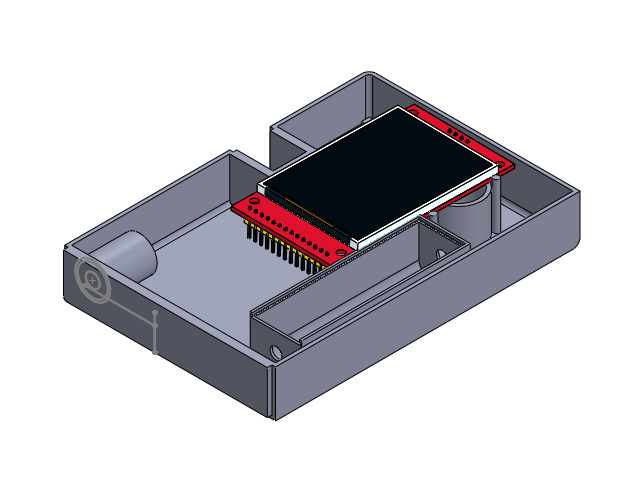
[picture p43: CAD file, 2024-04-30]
documents/3D Parts/Assem2.SLDASM
newone1
User Library-TFT Display 2,4inch

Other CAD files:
TrailGuard2.0/body_1.step.SLDPRT
TrailGuard2.0/marking_1.step.SLDPRT
Enclosure/top.SLDPRT
Enclosure/top.STL

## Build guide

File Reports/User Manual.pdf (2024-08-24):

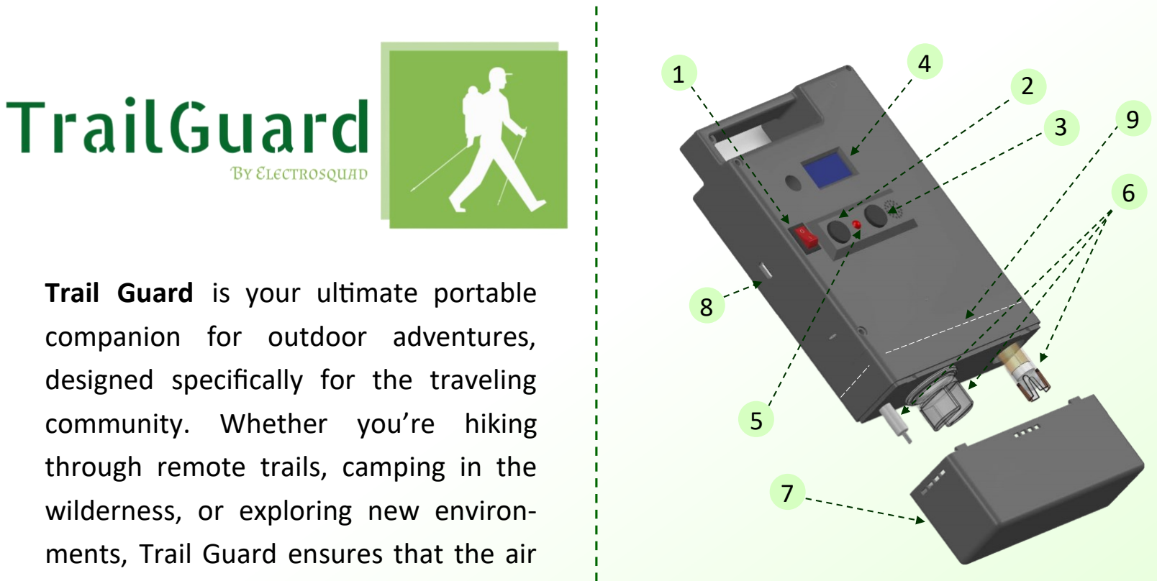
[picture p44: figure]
Trail Guard is your ultimate portable companion for outdoor adventures, designed specifically for the traveling community. Whether you’re hiking through remote trails, camping in the wilderness, or exploring new environ- ments, Trail Guard ensures that the air

you breathe and the water you drink are safe and of high quality. This compact and portable device combines advanced sensors to monitor both air and water quality, providing real-time data to help you make informed decisions on the go.

### Key Features

Comprehensive Monitoring: Tracks dust, temperature, humidity, gas levels, turbidity, TDS, and pH.

Portable: Lightweight and easy to carry for outdoor activities.

User-Friendly: Clear display with intuitive buttons and alarms for hazards.

Rechargeable Battery: Provides longlasting power for extended use.

Critical Condition Alarm: Alerts with sound and light when dangerous conditions are detected.

1. Power ON/OFF Switch
2. Navigation Button - To navigate to the desired quality parameter & to power on the display
3. Select Button - To select the desired quality parameter
4. Display
5. Indicator Light
6. Water Quality Sensors
7. Container Cap - To gather water for measure water quality
8. Charging Port
9. Submerge Level

### Technical Specifications

Power Supply: Rechargeable Lithium-Ion Battery
Measurement Range:
Dust Sensor: PM2.5 (0-500 μg/m³)
MQ2 Gas Sensor: CO2, CO, Methane, Butane, LPG(0-1000 ppm)
Temperature: -10°C to 50°C
Humidity: 10-90% RH
Turbidity: 0-3000 NTU
TDS: 0-500 ppm
pH: 0-14
Display: OLED display
Buttons: Two control buttons for navigation and settings
Operating Temperature: -10°C to 50°C

### Operating instruction

Measuring Air Quality

To measure air quality, place the device in the environment to be tested, ensuring the air intake is unobstructed for accurate dust readings. Position the device where gas presence is to be detected, and monitor the display for gas concentration levels. The temperature and humidity sensor continuously measures ambient conditions, with readings automatically updated on the display.

Measuring Water Quality

To measure water quality, submerge the turbidity, TDS, and pH sensors in the water sample, ensuring they are fully immersed. Wait for the readings to stabilize on the display for accurate measurements. Container cap can be used to gather the sample water.

### Appendix

Glossary of Terms
TDS: Total Dissolved Solids, a measure of the combined content of all inorganic and organic substances in water.
pH: A measure of how acidic or basic water is.
PM2.5: Particulate matter that is 2.5 micrometers or smaller in diameter.

Regulatory Standards
Sri Lanka national air and water quality standards & WHO standards

Environmental Considerations
Dispose of the device and its components according to local environmental regulations.

### Support

Service and Repair
For service and repair, contact authorized service centers.

Contact Details
Support Email: trailguard@gmail.com Phone: +94-75 520 8418

Charging the Battery

Use the micro USB cable to charge the device. Charge for up to 1.5 hours to reach full capacity.

### Safety Instructions

Handle the device with care and avoid exposing it to harsh environments beyond its operational limits.
Ensure the sensors are properly maintained for accurate readings.

Don’t submerge the device below the submerge level line.

trailguard@gmail.com | +94-75 520 8418

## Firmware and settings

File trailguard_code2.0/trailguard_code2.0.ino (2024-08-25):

#include <dht.h>
#include "DUST.h"
#include <SPI.h>
#include <Wire.h>
#include <Adafruit_GFX.h>
#include <Adafruit_SSD1306.h>

#define gas_pin 4
#define Dust_Apin A2
#define Dust_Dpin 3
#define Menu 7        
#define Select_Exit 9
#define turbidity_pin A0
#define ph_pin A1
#define TdsSensorPin A3
#define VREF 5.0      // analog reference voltage(Volt) of the ADC
#define SCOUNT  30  
#define DHT11_PIN 2

int analogBuffer[SCOUNT];    // store the analog value in the array, read from ADC
int analogBufferTemp[SCOUNT];
int analogBufferIndex = 0,copyIndex = 0;
float averageVoltage = 0,tdsValue,temperature = 25;
double phValue;
float volt;
float ntu;
int menuIndex = 0; 
int Oledpower = 0; 
int back = 0 ;
int temperature1,chk,humidity;
double gas_level,dustlevel;
float TDS_value, Ph_value, Turbidity;
bool manualOff = false;
unsigned long manualOffTime = 0;
const unsigned long manualOffDuration = 300000;
float TDS;

Adafruit_SSD1306 display(128, 64, &Wire, -1);
dht DHT;

float round_to_dp( float in_value, int decimal_place ){
  float multiplier = powf( 10.0f, decimal_place );
  in_value = roundf( in_value * multiplier ) / multiplier;
  return in_value;
}

int getMedianNum(int bArray[], int iFilterLen) {
      int bTab[iFilterLen];
      for (byte i = 0; i<iFilterLen; i++)
      bTab[i] = bArray[i];
      int i, j, bTemp;
      for (j = 0; j < iFilterLen - 1; j++) 
      {
      for (i = 0; i < iFilterLen - j - 1; i++) 
          {
        if (bTab[i] > bTab[i + 1]) 
            {
        bTemp = bTab[i];
            bTab[i] = bTab[i + 1];
        bTab[i + 1] = bTemp;
         }
      }
      }
      if ((iFilterLen & 1) > 0)
    bTemp = bTab[(iFilterLen - 1) / 2];
      else
    bTemp = (bTab[iFilterLen / 2] + bTab[iFilterLen / 2 - 1]) / 2;
      return bTemp;
}


const unsigned char myBitmap [] PROGMEM = {
	0x00, 0x00, 0x00, 0x00, 0x00, 0x00, 0x00, 0x00, 0x00, 0x00, 0x00, 0x00, 0x00, 0x00, 0x00, 0x00, 
	0x00, 0x00, 0x00, 0x00, 0x00, 0x00, 0x00, 0x00, 0x00, 0x00, 0x00, 0x00, 0x00, 0x00, 0x00, 0x00, 
	0x00, 0x00, 0x00, 0x00, 0x00, 0x00, 0x00, 0x00, 0x00, 0x00, 0x00, 0x00, 0x00, 0x00, 0x00, 0x00, 
	0x00, 0x00, 0x00, 0x00, 0x00, 0x00, 0x00, 0x00, 0x00, 0x00, 0x00, 0x00, 0x00, 0x00, 0x00, 0x00, 
	0x00, 0x00, 0x00, 0x00, 0x00, 0x00, 0x00, 0x00, 0x00, 0x00, 0x00, 0x00, 0x00, 0x00, 0x00, 0x00, 
	0x00, 0x00, 0x00, 0x00, 0x00, 0x00, 0x00, 0x00, 0x00, 0x00, 0x00, 0x00, 0x00, 0x00, 0x00, 0x00, 
	0x00, 0x00, 0x00, 0x00, 0x00, 0x00, 0x00, 0x00, 0x00, 0x00, 0x00, 0x00, 0x00, 0x00, 0x00, 0x00, 
	0x00, 0x00, 0x00, 0x00, 0x00, 0x00, 0x00, 0x00, 0x00, 0x00, 0x00, 0x00, 0x00, 0x00, 0x00, 0x00, 
	0x00, 0x00, 0x00, 0x00, 0x00, 0x00, 0x00, 0x00, 0x00, 0x00, 0x00, 0x00, 0x00, 0x00, 0x00, 0x00, 
	0x00, 0x00, 0x00, 0x00, 0x00, 0x00, 0x00, 0x00, 0x00, 0x00, 0x00, 0x00, 0x00, 0x00, 0x00, 0x00, 
	0x00, 0x00, 0x00, 0x00, 0x00, 0x00, 0x00, 0x00, 0x00, 0x00, 0x00, 0x00, 0x00, 0x00, 0x00, 0x00, 
	0x00, 0x00, 0x00, 0x00, 0x00, 0x00, 0x00, 0x00, 0x00, 0x00, 0x00, 0x00, 0x00, 0x00, 0x00, 0x00, 
	0x00, 0x00, 0x00, 0x00, 0x00, 0x00, 0x00, 0x00, 0x00, 0x00, 0x03, 0xff, 0xff, 0xff, 0xff, 0xfc, 
	0x00, 0x00, 0x00, 0x00, 0x00, 0x00, 0x00, 0x00, 0x00, 0x00, 0x03, 0xff, 0xff, 0xff, 0xff, 0xfc, 
	0x00, 0x00, 0x00, 0x00, 0x00, 0x00, 0x00, 0x00, 0x00, 0x00, 0x03, 0xff, 0xff, 0xff, 0xff, 0xfc, 
	0x00, 0x00, 0x00, 0x00, 0x00, 0x00, 0x00, 0x00, 0x00, 0x00, 0x03, 0xff, 0xff, 0xfd, 0xff, 0xfc, 
	0x00, 0x00, 0x00, 0x00, 0x00, 0x00, 0x00, 0x00, 0x00, 0x00, 0x03, 0xff, 0xff, 0xf0, 0xff, 0xfc, 
	0x00, 0x00, 0x00, 0x00, 0x00, 0x00, 0x00, 0x00, 0x00, 0x00, 0x03, 0xff, 0xff, 0xf0, 0x3f, 0xfc, 
	0x00, 0x00, 0x00, 0x00, 0x00, 0x00, 0x00, 0x00, 0x00, 0x00, 0x03, 0xff, 0xff, 0xf0, 0xff, 0xfc, 
	0x00, 0x00, 0x00, 0x00, 0x00, 0x00, 0x00, 0x00, 0x00, 0x00, 0x03, 0xff, 0xff, 0xf0, 0xff, 0xfc, 
	0x00, 0x00, 0x00, 0x00, 0x00, 0x00, 0x00, 0x00, 0x00, 0x00, 0x03, 0xff, 0xfe, 0x30, 0xff, 0xfc, 
	0x00, 0x00, 0x00, 0x00, 0x00, 0x00, 0x00, 0x00, 0x00, 0x00, 0x03, 0xff, 0xfe, 0x01, 0xff, 0xfc, 
	0x00, 0x00, 0x00, 0x00, 0x00, 0x00, 0x00, 0x00, 0x00, 0x00, 0x03, 0xff, 0xfe, 0x00, 0xff, 0xfc, 
	0x00, 0x00, 0x00, 0x19, 0x80, 0x20, 0x00, 0x00, 0x00, 0x01, 0x83, 0xff, 0xfc, 0x00, 0x7f, 0xfc, 
	0xff, 0x80, 0x00, 0x01, 0x81, 0xb8, 0x00, 0x00, 0x00, 0x01, 0x83, 0xff, 0xfc, 0x00, 0x7f, 0xfc, 
	0x08, 0x00, 0x00, 0x01, 0x83, 0x10, 0x00, 0x00, 0x00, 0x01, 0x83, 0xff, 0xfc, 0x00, 0x7f, 0xfc, 
	0x08, 0x1b, 0x1e, 0x19, 0x86, 0x00, 0xc6, 0x1e, 0x1b, 0x1d, 0x83, 0xff, 0xfc, 0x00, 0x7f, 0xfc, 
	0x08, 0x1f, 0x3f, 0x19, 0x86, 0x00, 0xc6, 0x3f, 0x1f, 0x3f, 0x83, 0xff, 0xfe, 0x00, 0x3f, 0xfc, 
	0x08, 0x18, 0x03, 0x19, 0x86, 0x00, 0xc6, 0x03, 0x18, 0x31, 0x83, 0xff, 0xfe, 0x00, 0x1f, 0xfc, 
	0x08, 0x18, 0x03, 0x19, 0x86, 0x38, 0xc6, 0x03, 0x18, 0x61, 0x83, 0xff, 0xfe, 0x01, 0x07, 0xfc, 
	0x08, 0x18, 0x3b, 0x19, 0x86, 0x18, 0xc6, 0x3b, 0x18, 0x61, 0x83, 0xff, 0xfe, 0x01, 0x87, 0xfc, 
	0x08, 0x18, 0x33, 0x19, 0x86, 0x08, 0xc6, 0x33, 0x18, 0x61, 0x83, 0xff, 0xfe, 0x01, 0xe7, 0xfc, 
	0x08, 0x18, 0x23, 0x19, 0x83, 0x08, 0xc6, 0x63, 0x18, 0x31, 0x83, 0xff, 0xfe, 0x40, 0xef, 0xfc, 
	0x08, 0x18, 0x37, 0x18, 0xc3, 0x98, 0xe6, 0x37, 0x18, 0x3d, 0x83, 0xff, 0xfe, 0x40, 0xef, 0xfc, 
	0x08, 0x18, 0x35, 0x18, 0xe1, 0xb0, 0x76, 0x35, 0x18, 0x1d, 0x83, 0xff, 0xf9, 0xc0, 0x5f, 0xfc, 
	0x00, 0x00, 0x00, 0x00, 0x00, 0x00, 0x00, 0x00, 0x00, 0x00, 0x03, 0xff, 0xf3, 0x80, 0x5f, 0xfc, 
	0x00, 0x00, 0x00, 0x00, 0x00, 0x00, 0x00, 0x00, 0x00, 0x00, 0x03, 0xff, 0xe7, 0x80, 0x3f, 0xfc, 
	0x00, 0x00, 0x00, 0x00, 0x00, 0x00, 0x00, 0x00, 0x00, 0x00, 0x03, 0xff, 0x9f, 0x04, 0x1f, 0xfc, 
	0x00, 0x00, 0x00, 0x00, 0x00, 0x00, 0x00, 0x00, 0x00, 0x00, 0x03, 0xff, 0x3f, 0x0e, 0x1f, 0xfc, 
	0x00, 0x00, 0x00, 0x00, 0x00, 0x00, 0x00, 0x00, 0x00, 0x00, 0x03, 0xfe, 0x7f, 0x0e, 0x0f, 0xfc, 
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
};

void setup() { 

  Serial.begin(9600);
  
  pinMode(Menu, INPUT);
  pinMode(Select_Exit, INPUT);
  
  pinMode(11, OUTPUT);
  pinMode(13,OUTPUT);
  pinMode(10, OUTPUT);
  pinMode(12, OUTPUT);
  pinMode(TdsSensorPin,INPUT);

  

  digitalWrite(12,HIGH);
  
  display.begin(SSD1306_SWITCHCAPVCC, 0x3C);
  display.clearDisplay();
  display.setTextColor(SSD1306_WHITE);
  display.drawBitmap(0, 0, myBitmap, 128, 64, SSD1306_WHITE);
  display.display();
  delay(2000);
}

void loop() {
  
  chk = DHT.read11(DHT11_PIN);
  temperature1 = DHT.temperature;
  humidity = DHT.humidity;
  
  gas_level = digitalRead(gas_pin);

  dustlevel= dust_density(Dust_Apin,Dust_Dpin);
  
  if ((gas_level==0.00 || dustlevel>300) && (manualOff == false)){
    digitalWrite(13,HIGH);

  }
  else{
    digitalWrite(13,LOW);
  }

  if ((manualOff == true) && (millis() - manualOffTime >= manualOffDuration)) {
    manualOff = false;
  }

  
  
  if (menuIndex == 0){
    display.clearDisplay();
    display.display();
  }

  if ((menuIndex == 1) && (Oledpower == 1) ){
    
    display.clearDisplay();
    display.setTextSize(1);
    
    display.setCursor(0, 16);
    display.print(temperature1);
    display.print(F(" C"));
    Serial.print(temperature1);
    Serial.println(F(" C"));
    
    display.setCursor(0, 32);
    display.print(humidity);
    display.print(F(" %"));
    Serial.print(humidity);
    Serial.println(F(" %"));
    
    display.display();
  }
  
  if (digitalRead(Menu)== HIGH && (Oledpower == 0)){
    menuIndex = 1;
    Oledpower = 1;
    delay(150);
  }
  
  if (digitalRead(Menu)== HIGH && (Oledpower == 1)){
    menuIndex = menuIndex + 1;
    if (menuIndex == 10){
      menuIndex = 2;
    }
    delay(150);
  }

  if ((menuIndex != 0) && (menuIndex != 1) && (Oledpower == 1) && (back == 0) ){
    // Serial.print(menuIndex);
    
      if (menuIndex < 6){
        display.clearDisplay();
        display.setCursor(0, 8 + ((menuIndex-2) * 16));
        display.print(F("> "));
        display.setCursor(10, 8);
        display.print(F("Water Quality"));
        display.setCursor(10, 24);
        display.print(F("pH value"));
        display.setCursor(10, 40);
        display.print(F("TDS value"));
        display.setCursor(10, 56);
        display.print(F("Turbidity"));
        display.display();
        
      }
      else{
        display.clearDisplay();
        display.setCursor(0, 8 + ((menuIndex-6) * 16));
        display.print(F("> "));
        display.setCursor(10, 8);
        display.print(F("Dust density"));
        display.setCursor(10, 24);
        display.print(F("Buzzer off"));
        display.setCursor(10, 40);
        display.print(F("Back"));
        display.setCursor(10, 56);
        display.print(F("Display off"));
        display.display();
        
      }
    
  }
    if((digitalRead(Select_Exit) == HIGH) && (menuIndex != 0) && (menuIndex != 1) && (Oledpower == 1) ){
    delay(200);
    back= (back + 1 ) % 2 ; 
    if (back == 1){ 
      if ( menuIndex == 2 ){
        digitalWrite(11, HIGH);
      

        for (int i=30 ; i>=0 ; i--){

          int analogValue = analogRead(A1); 

          if (i<=30 && i>10){
            digitalWrite(10,LOW);
            if (analogValue == 512) {
              phValue = 7; 
            } 
            else if (analogValue > 512) {
              phValue = 7-((float)analogValue-512)/512*7;
            }
            else {
              phValue = 7+((512-(float)analogValue)/512*7);
            }
          }

          else{
	    digitalWrite(10,HIGH);
            Serial.println(analogRead(A3));
            int analogValue = 0;
            for (int i = 0; i < SCOUNT; i++) {
              analogValue += analogRead(TdsSensorPin);
              delay(10);
            }
            analogValue /= SCOUNT; // Average the samples

            float voltage = analogValue * (VREF / 1024.0); // Convert analog value to voltage
            float compensationCoefficient = 1.0 + 0.02 * (temperature - 25.0); // Temperature compensation
            float compensatedVoltage = voltage / compensationCoefficient; // Apply compensation
            float tdsValue = (133.42 * pow(compensatedVoltage, 3) 
                            - 255.86 * pow(compensatedVoltage, 2) 
                            + 857.39 * compensatedVoltage) * 0.5; 
            TDS=tdsValue;
            Serial.print(" ");
            Serial.println(tdsValue);
            
          
            
            volt = 0;

            for(int i=0; i<800; i++){
              volt += ((float)analogRead(turbidity_pin)/1024)*5;
            }
            volt = volt/800;
            volt = round_to_dp(volt,2);

            if(volt < 2.5){
              ntu = 300;}
            else{
              ntu = -112.04*square(volt)+574.23*volt-435.38; 
            }
          }
          display.clearDisplay();
          display.setCursor(0, 16);
          display.print(F("Wait "));
          display.print(i);
          display.print(F(" s"));
          display.display();
          delay(1000);
        }


        digitalWrite(11, LOW);
        if (TDS<0){
          TDS=0;
        }

        if (phValue<0){
          phValue=0;
        }

        if (ntu<0){
          ntu=0;
        }

        display.clearDisplay();
        if ((phValue > 6 && phValue < 8.5)  && (TDS < 500) && (ntu < 5 )) {
          display.setCursor(0, 16);
          display.print(F("Drinkable"));
        }
        else{
          display.setCursor(0, 16);
          display.print(F("Not Drinkabe"));
        } 
        
        if (phValue > 6 && phValue < 9) {

          display.setCursor(0, 32);
          display.print(F("Bathable"));
        }
        else{
          display.setCursor(0, 32);
          display.print(F("Not Bathable"));
        }
        display.display();
        

      }
      else if ( menuIndex == 3 ){
        display.clearDisplay();
        display.setCursor(0, 16);
        display.print(phValue);
        display.display();
      }
      else if ( menuIndex == 4 ){
        display.clearDisplay();
        display.setCursor(0, 16);
        display.print(TDS);
        display.display();
      }
      else if ( menuIndex == 5 ){
        display.clearDisplay();
        display.setCursor(0, 16);
        display.print(ntu);
        display.display();
      }
      else if ( menuIndex == 6 ){

        
        display.clearDisplay();
        if (dustlevel<0){
          dustlevel = 7.9 ;
        }
        display.setCursor(0, 16);
        display.print(dustlevel);
        display.print(" ug/m3");
        display.display();
          
      
      }
      else if ( menuIndex == 7 ){
        digitalWrite(13,LOW);
        manualOff = true;
        manualOffTime = millis();
        menuIndex = 1;
        back = 0;
      }

      else if ( menuIndex == 8 ){
        menuIndex = 1 ;
        back = 0 ;
      }
      else{
        menuIndex = 0 ;
        Oledpower = 0 ;
        back = 0 ;
      }
    }
  }
  
}

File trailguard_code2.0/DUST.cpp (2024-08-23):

#include "DUST.h"
#include <Arduino.h>

int samplingTime = 280; // time required to sample signal coming out   of the sensor
int deltaTime = 40; // 
int sleepTime = 9680;

float voMeasured = 0;
float calcVoltage = 0;
float dustDensity = 0;


double dust_density(int measurePin,int ledPower){
  pinMode(ledPower,OUTPUT);
  digitalWrite(ledPower,LOW); // power on the LED
  delayMicroseconds(samplingTime);
  
  voMeasured = analogRead(measurePin); // read the dust value
  
  delayMicroseconds(deltaTime);
  digitalWrite(ledPower,HIGH); // turn the LED off
  delayMicroseconds(sleepTime);
  // 0 - 5V mapped to 0 - 1023 integer values

  // recover voltage
  calcVoltage = voMeasured * (5.0 / 1024.0);

  // linear eqaution taken from http://www.howmuchsnow.com/arduino/airquality/
  // Chris Nafis (c) 2012
  dustDensity = (170 * calcVoltage - 0.1);
  return dustDensity; // unit: ug/m3
}

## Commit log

2024-04-17 added controller
    [TrailGuard1.0.PrjPcb, controller.PcbDoc, controller.PcbLib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]
2024-04-18 Started Controller Design
    [TrailGuard1.0.PrjPcb, controller.PcbDoc, controller.PcbLib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]
2024-04-18 Finish basic Microcontroller with 1206 SMDs
    [controller.SchDoc]
2024-04-19 Added some research and schematic documents
2024-04-21 3d model
    [Part1.SLDPRT]
2024-04-22 Add files via upload
    enclosure
    [Part1.SLDPRT]
2024-04-22 Add files via upload
    battery
2024-04-22 added jst connectors to pcb
    [Controller.PcbDoc, TrailGuard1.0.PrjPcb, controller.SchDoc]
2024-04-22 dust sensor connector done
    [Controller.PcbDoc, TrailGuard1.0.PrjPcb, controller.SchDoc]
2024-04-25 add connectors and modules to PCB
    [Black Heatsink - Dimensions 25 x 12.6 x 6.5 mm. Hole at 18.3mm. Pin fixing.stp, TrailGuard1.0.PcbLib, TrailGuard1.0.PrjPcb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]
2024-04-30 L shape PCB
    [TrailGuard1.0.PrjPcb, controller.SchDoc]
2024-05-01 mosfet switching
    [Controller.PcbDoc, controller.SchDoc]
2024-05-01 added schematic
2024-05-02 new PCB
    [Controller.PcbDoc, Header 10 pins.step, SSD1306_OLED_Display(128x64).step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]
2024-05-04 Comonent placement on PCB
    [TrailGuard1.0.SCHLIB, TrailGuard2.0.PrjPcb, trailGuard.PcbDoc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]
2024-05-04 PCb Routing Done
    [trailGuard.PcbDoc]
2024-05-05 PCB Labels Naming
    [red-led-5mm.SLDPRT, trailGuard.PcbDoc]
2024-05-11 New PCB Design
    [trailGuard.PcbDoc, trailGuard.SchDoc]
2024-05-14 Manual Routing
    [trailGuard.PcbDoc]
2024-08-18 Create Enclosure
2024-08-18 Added top part of enclosure
    [top.SLDPRT, top.STL]
2024-08-18 Added top part of the enclosure
    [top.SLDPRT, top.STL]
2024-08-19 Final PCB
    [trailGuard.PcbDoc]
2024-08-19 Deleted TrailGurad1.0
    [Controller.PcbDoc, TrailGuard1.0.PcbLib, TrailGuard1.0.PrjPcb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]
2024-08-19 PCB BOM
    [TrailGuard2.0.PrjPcb]
2024-08-23 bottom part
    [bottom.SLDPRT]
2024-08-23 bottom cup
    [cup.SLDPRT]
